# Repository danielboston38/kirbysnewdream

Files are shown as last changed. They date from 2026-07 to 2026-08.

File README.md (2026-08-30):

# Link to Video

A replacement for the RF modulator in the original Nintendo Entertainment System (NES-001). Drops into the stock RF module slot inside the shell and provides composite video and USB-C power in place of a part that fails by design.

<a href="https://certification.oshwa.org/us002842.html">
  OSHWA Certified Open Source Hardware UID US002842
</a>

> **Renamed.** This project shipped its first revision as **Kirby's New Dream**.
> From v2 onward it is **Link to Video**. Anything referring to the old name —
> the v1 board silkscreen, the 2026-07-16 PCBWay fab package under
> [`pcbway_production/`](./pcbway_production), and older commits — is the same
> project. The GitHub repository was renamed to match; the previous
> `kirbysnewdream` URL still redirects.

## Why this board exists

The NES-001's RF modulator already carries composite video, so this isn't about
adding an output the console lacks. It's about replacing a part that reliably
destroys itself.

Nintendo packed the modulator's regulator and RF stages into a sealed can with no
ventilation. It cooks its own electrolytics, they leak, and the electrolyte eats
the traces underneath. Across three NES-001 units on the author's bench, **all
three** had modulator failures from exactly this — including a Mitsumi unit that
looked pristine externally and had every capacitor leaking inside.

So the modulator is a consumable on a forty-year-old console, and the usual
options are to recap a corroded board or to fit an aftermarket board. This is the
second option, with the power input modernised to USB-C while the slot is open.

## Disclosure

This project's schematic design, debugging, and documentation were developed with the assistance of AI (Claude, by Anthropic). All hardware was hand-assembled, tested, and validated by the author. Use, review, and verify independently before building.

## Status

🟡 First prototype assembled and power-tested successfully (5V confirmed clean on rail, no protection trips). Video output path **does not work on v1 hardware** — traced to a schematic defect in which Q1's emitter node was shorted to the +5V rail (see Known Issues). Fixed in source; v1 boards need a rework.

<!-- Swap the line above for something like this once video's confirmed:
🟢 Fully validated — power and composite video both confirmed working on hardware.
-->

## Features

- USB-C power input (power only — no data lines)
- Composite video output
- Active overcurrent protection — TPS2553 eFuse with a ~1.18 A resistor-programmed limit, soft-start and thermal shutdown, backed by a polyfuse
- Fits inside the original NES shell at the stock RF module location
- Bring-up test points for video, ground, +5V and audio, labelled on the silkscreen
- Feed header for an external 8-pin mini-DIN RGB connector (NESRGB)
- All resistor and capacitor values printed on the silkscreen — the v1 board had four identical unlabelled axial footprints carrying four different values, which caused three separate wrong-resistor build errors
- 2-layer PCB, designed in KiCad

## Power path

```
USB-C  ──  F1 polyfuse  ──  U1 TPS2553 eFuse  ──  +5V rail  ──  J4.3 → NES
  VBUS      2.0A hold        ~1.18A limit          C1 100µF
            3.8A trip        soft-start            D1 TVS
            (backup)         thermal shutdown
```

F1 alone trips at 3.8 A, which protects nothing on a console that draws
roughly 0.5–0.7 A. U1 is the real protection; F1 stays as a backup in case
the eFuse ever fails short.

The current limit is set by R6 on U1's ILIM pin. The relationship is
**inverse** — a larger resistor gives a *lower* limit:

| R6 | Limit (typ) |
|---|---|
| 15 kΩ | 1700 mA |
| 20 kΩ | 1295 mA |
| **22 kΩ (fitted)** | **~1180 mA** |
| 49.9 kΩ | 520 mA |
| 210 kΩ | 130 mA |

Roughly I_OS(A) ≈ 25.9 / R6(kΩ), valid over TI's recommended 15 kΩ–232 kΩ.

U1's EN (pin 3) is active-high and tied to its own input, so the switch is
always on. FAULT (pin 4) is an open-drain output left unconnected — there is
nothing inside a closed NES shell to indicate to. If you want fault
indication, it can sink 25 mA directly.

A useful side effect: D1 is a unidirectional TVS, so fitting it backwards
puts a forward-biased diode across the 5 V rail. Before U1 that was a near
short relying on a polyfuse taking seconds to react. Now the eFuse current-
limits it at ~1.18 A and thermally shuts down, so the mistake is
self-limiting rather than destructive.

## Test points (v2)

Four through-hole test points (2.0 mm pad, 1.0 mm drill) for bring-up. They accept
a 0.64 mm square header pin, so you can solder pins in and use scope grabbers.

The silkscreen carries the signal name only — `VIDEO`, `GND`, `+5V`, `AUDIO` — so
the board reads without this table. The refdes lives on F.Fab for the fab drawings.
(On v2's first pass this was backwards: the signal names were on F.Fab, which never
reaches the physical board, so the silkscreen said only `TP1`–`TP4`.)

| TP  | Net | Location (mm) | Notes |
|-----|---|---|---|
| TP1 | `/VIDEO_OUT` | 62.0, 60.0 | Jack-side video, i.e. after C2 and the 75 Ω series R5 — what the TV actually sees. A high-impedance probe reads roughly double the terminated amplitude. |
| TP2 | `GND` | 58.5, 60.0 | Straight into the B.Cu ground pour. |
| TP3 | `/5V` | 52.0, 43.1 | Sits directly on the protected 5 V trunk, downstream of F1 and the TPS2553. |
| TP4 | `/AUDIO_OUT` | 65.9, 28.35 | Audio pass-through between J4 pin 2 and J2. |

The whole back layer is a ground pour, so TP2's position is a convenience, not a
constraint — you can clip a ground lead to any B.Cu feature.

To probe the buffer itself rather than its output, use Q1's emitter leg directly;
there is no test point on `Net-(Q1-E)`.

## RGB output (v2)

Provision for the [NESRGB](https://etim.net.au/nesrgb/) board's RGB connector —
the Micomsoft XRGB-mini Framemeister 8-pin mini-DIN standard.

The connector itself is **not** on this board. The NESRGB kit ships it as a
panel-mount jack that epoxies into a 12 mm hole in the shell, so this board just
feeds it. R/G/B run directly from the NESRGB to the connector; we supply the
other three pins on **J5**:

| J5 pin | Net | mini-DIN pin | |
|---|---|---|---|
| 1 | `/RGB_VIDEO` | 3 | Composite video / sync, 75 Ω terminated |
| 2 | `GND` | 4 | |
| 3 | `/5V` | 5 | Downstream of the TPS2553, so it is current-limited |

mini-DIN pins 1 and 2 are N/C; pins 6, 7 and 8 are Blue, Green and Red from the
NESRGB. Note the standard carries no audio — that stays on the RCA jack, which is
deliberate on Tim Worthington's part (it keeps video noise out of the audio).

**Why R7 exists.** The video buffer's output (`/VIDEO_BUF`, Q1's emitter through
C2) now feeds two outputs. Each needs its own 75 Ω source termination: R5 for the
RCA jack, R7 for the mini-DIN. Tying both to one resistor would put two 75 Ω loads
in parallel and halve the amplitude whenever both cables are plugged in.

**One output at a time.** Composite and RGB are an either/or — the design does not
target using both at once. Whichever cable is plugged sees a correct 75 Ω source,
and the unused branch is an unloaded stub.

If both are ever plugged in simultaneously, R7 means each still gets a properly
terminated 75 Ω source rather than the halved amplitude you'd get from sharing one
resistor. Q1's drive is the limit in that case, and it is why **R1 is 220 Ω from
v2** rather than the original 330 Ω. Simulated in ngspice with 2 Vpp at the tap
and both outputs terminated: at 330 Ω the follower clips the positive (white)
peaks by 33 %, at 220 Ω by 11 %. With a single output loaded — the supported
mode — 220 Ω is clean and symmetric (+0.439 / −0.447 V at the jack). Simulated,
not measured on hardware, and still not a supported mode.

## Hardware

- Designed in KiCad (schematic + PCB source included in this repo)
- Fabricated via PCBWay
- See [BOM.csv](./BOM.csv) for full parts list

## Build Notes / Known Issues (v1)

- **Q1 emitter node shorted to +5V (breaks video).** Q1's emitter is clamped to the rail, so C2 couples +5V — not video — into R5/J3. The exact wiring differs by revision: in the repo's pre-v1.1 source R1 had *both* ends on `/5V`, while the fabbed 2026-07-16 boards have R1 pad 1 on `/5V` and pad 2 on a separate net with C1 only. Root cause: an R2 (110Ω) was deleted from the schematic on 2026-07-04, and KiCad merged the two leftover collinear wire stubs into one wire, welding the emitter node to `/5V`. Fixed in source as of v1.1. **Rework for an existing board** (applies to the boards fabbed from the 2026-07-16 gerbers, whose IPC netlist reads `/5V = J4.3, F1.1, R1.1, Q1.1, C2.1, D1.1` and `Net-(C1-Pad1) = R1.2, C1.1`):

That revision has two defects — Q1's emitter is clamped to the rail, *and* C1 only reaches the rail through R1, so the bulk cap decouples nothing. Both are fixed together:

**Confirm the diagnosis before you cut.** Power off, unplugged, caps discharged.
Probe +5 V at J4 pin 3 or D1's K-marked lead. Two measurements, mirror images of
each other:

| Measurement | Defective board | Correctly wired |
|---|---|---|
| Q1 emitter → +5 V | **~0 Ω** | ~330 Ω (R1) |
| C1 **+** terminal → +5 V | **~330 Ω** (stranded behind R1) | ~0 Ω |

After the rework these swap. To identify Q1's legs without relying on the TO-92
orientation: the leg reading 0 Ω to GND is the collector, the leg with continuity
to J4 pin 1 is the base, and the remaining one is the emitter.

Two tests that look useful but are not:

- **Emitter → J3 tip.** C2 blocks DC, so this reads open either way.
- **C1 + → Q1 emitter.** Reads ~330 Ω on a good board *and* a bad one, because R1
  sits between them in both wirings. It cannot distinguish the two.

Powered, the fastest single check is DC at Q1's emitter: roughly 1.5–3 V if
correct, sitting at exactly the rail voltage if shorted.

**R1's left pad is a star point.** Three things meet there: F1 (the source), the
D1 + J4.3 branch (the load), and Q1's emitter. The two incoming rail traces are
*collinear*, so a single cut severs both — which is why this needs **two**
jumpers, not one.

1. **Cut** the 0.8 mm trace leaving R1's left pad toward the **upper left**, about
   5–8 mm from the pad. Leave the trace entering from the upper right — that is
   Q1's emitter and must stay. Stay below the level of D1's cathode; above that
   point only one of the two overlapping traces is present, and you need both cut.

2. **Two jumpers.** The cut leaves three islands that must all become one rail:

   | Island | Pads |
   |---|---|
   | A | C1's **+** pad, R1's **right** pad |
   | B | F1 pad 1 (left pad, trace toward D1 — not the USB-C side) |
   | C | D1's cathode (K), J4 pin 3 |

   Any two wires joining all three work. One wire per pad:
   - **C1+ → F1 pad 1** (~14 mm)
   - **R1's right pad → D1 cathode** (~25 mm)

   Do this with R1 removed — its right pad is far easier to solder empty.

3. **Fit R1 = 300–330 Ω.** Check the part before fitting: R1, R3, R4, R5 (and R7
   on v2) all share the same `R_Axial_DIN0207` footprint in four different values,
   and the v1 silkscreen prints no values. At least one board was built with a
   5.1 kΩ from the R3/R4 pile in R1, which gives ~0.6 mA of standing current
   instead of ~9 mA — enough to look plausible and still produce no usable video.

4. **Confirm R5 (75Ω) is populated.** Across R5's own pads should read ~75 Ω; it
   has no parallel path in circuit (C2 blocks DC on one side, the jack is open on
   the other), so it doubles as a meter sanity check.

5. **Fit the transistor last.** Powering the board before the cut is done drives
   Q1 into saturation from the rail straight to ground with no current limit — see
   below.

Verify with a meter before powering: R1's left pad to D1 cathode must now read
**open**; R1's left pad to F1 pad 1 must read **~330Ω** through R1; R1's left pad
must still show continuity to Q1's emitter and C2 pin 1; and D1's cathode must
read **~0 Ω** to J4 pin 3 *and* to F1 pad 1. Powered, Q1's emitter should sit near
1.5–3V — a reading of 5V means the cut did not take.

**The short destroys transistors.** With the emitter clamped to +5 V and the base
at the NES's video level, the B-E junction is forward-biased by 3–4 V, so Q1
saturates with its collector tied directly to ground and nothing limiting the
current. Q1 is a 150 mA part; F1 does not trip until 3.8 A. Every power-up in that
state risks another transistor, which is the likely fate of the first one.
- F1 (polyfuse) footprint field in KiCad is mislabeled as a polarized capacitor footprint despite correct value — cosmetic/documentation issue only, does not affect function. Fix planned for v2.
- Video/audio RCA jack mounting holes are slightly asymmetric — cosmetic only, doesn't affect NES shell fit.
- v1 silkscreen doesn't include component value labels or Q1 pin markers (E/C/B). **Values are on the silkscreen from v2.** On v1 this caused three separate wrong-resistor errors in R1 (a 5.1kΩ and an 820Ω both fitted before the right value went in) because R1/R3/R4/R5/R7 share one footprint across four values. Q1 pin markers are still outstanding.
- **D1 does not protect U1.** The fitted TVS is a Littelfuse 1.5KE6.8A: stand-off 5.80 V, breakdown 6.45–7.14 V at 10 mA, clamping 10.5 V at 144.8 A. The TPS2553's absolute maximum on IN and OUT is 7 V, so the TVS has barely begun conducting by the time the eFuse is already out of spec, and under a real surge it lets the rail reach 10.5 V. D1 protects the console downstream; it will not save U1. Repositioning D1 doesn't help — both U1 pins share the same 7 V rating — and no avalanche TVS clamps below 7 V while standing off USB-C's 5.5 V worst case. Proper protection needs a switch with integrated overvoltage cutoff. Deferred to v3 — v2 ships with this gap.
- D1's symbol (`Diode:1.5KExxA`) names both pins A1/A2 and draws no cathode — KiCad uses identical pin naming for the unidirectional and bidirectional variants of this part. Polarity comes only from the footprint silkscreen band, which is at the pad-1 (+5 V) end and is correct. Watch this when hand-assembling.

## Video input biasing

Q1's base is DC-coupled straight to the NES video line, with no bias network on
this board. That is deliberate, and it took a long bench session to establish
why it works.

**The NES mainboard supplies a 1 kΩ pulldown on its video output pin.** Measured
in circuit at 0.999 kΩ, identical with the meter leads both ways — a real
resistor, not a semiconductor junction. Q1's base sources roughly 46 µA, which
that 1 kΩ absorbs in about 46 mV. The base cannot float up and Q1 cannot cut off.

This is the same reason Nintendo's own modulator has no base pulldown either. It
also matches the load Nintendo presented on that pin: a 330 Ω series resistor
into a 5.6 kΩ / 330 Ω divider, roughly 500 Ω in total. The NES is built to drive
a few hundred ohms.

**So no base pulldown, and no input coupling cap.** If you are adapting this
design to something other than an NES-001, measure that pin to ground first —
if it reads open, you need a pulldown (~47 kΩ) and this board does not have one.

**R2 (330 Ω) is not a bias resistor.** It sits in series between J4 pin 1 and
Q1's base, mirroring the 330 Ω Nintendo places in the same position. Against
Q1's ~21 kΩ base input impedance it costs nothing in signal terms; what it buys
is fault-current limiting into the base-emitter junction, whose reverse rating
is only 5 V.

## Design checks

Two safety nets sit alongside ERC and DRC, both aimed at faults this board has
actually shipped with.

### `tools/check_nets.py`

```
python3 tools/check_nets.py
```

Exports the schematic netlist, reads the PCB's pad nets, confirms the two agree,
and asserts a set of invariants — chief among them that **Q1's emitter is not on
any power net**. That was the v1 fault: the emitter follower's output was tied
to +5V along with J4.3, D1.1 and F1.1, so Q1 saturated into a grounded collector
with nothing limiting the current. It destroyed a transistor on every power-up.

**ERC and DRC both passed cleanly on that board.** Neither can see that a net is
*wrong*, only that it is internally consistent — which is exactly why this check
exists. Run it before generating a fab package. Gerbers carry no net information,
so once you have them the mistake is invisible.

### `nes_power_video.kicad_dru`

Custom DRC rules covering the geometric half: extra clearance between Q1's
emitter and base nodes and the supply rails, and between the two USB-C
configuration channels. These catch the layout-adjacency version of the same
mistakes. They cannot catch a wrong net assignment — DRC has no view of design
intent — which is what the script above is for.

## Assembly

<!-- Add step-by-step or reference photos here once you've got a documented build process -->

Refer to BOM.csv for exact part values and footprints. Every component carries
its sourcing data in two places, kept in step: the `Manufacturer`, `MPN`,
`LCSC`, `Supplier Link` and `Datasheet` fields on the schematic symbol, and
the matching columns in `BOM.csv`. Jellybean passives have no manufacturer
part number by design — they carry a `Spec` field instead (tolerance, rating,
package) and any part meeting it will do. To pull the fields straight out of
the schematic:

```
kicad-cli sch export bom --group-by '' \
    --fields 'Reference,Value,Manufacturer,MPN,LCSC,Datasheet,Supplier Link,Spec' \
    -o bom.csv nes_power_video.kicad_sch
```

Key notes:
- D1 (zener/TVS): cathode (banded end) toward VBUS/+5V side. From v2 the
  silkscreen prints the value actually fitted, `1.5KE6.8A`; before that it
  printed the generic KiCad symbol name `1.5KExxA`, which is not orderable.
- Q1 (**2SA733**, PNP): flat side facing viewer, leads down = Emitter-Collector-Base, left to right.
  This replaces the 2SA1015/KSA1015, **both of which are end of life** (checked 2026-08-29): MCC's
  `2SA1015-GR-AP` is stocked at Mouser but flagged End of Life, and every onsemi `KSA1015` reads
  Obsolete on DigiKey, available only through Rochester Electronics' last-time-buy channel. The
  2SA733 is in current production, shares the E-C-B pin order exactly so it drops straight in, and is
  a better part for a video buffer: f_T 190 MHz typ against the 2SA1015's 80 MHz, C_ob 2–3 pF, P_C
  750 mW, with the same V_CEO −50 V / I_C −150 mA / V_EBO −5 V — so R2 still guards the base-emitter
  junction exactly as before. Buy the UTC `2SA733L-P-T92-B` from LCSC (**C5310429**, ~$0.035); rank P
  is hFE 200–400, which matches the ~46 µA base current measured on the bench, so the bias point does
  not move. DigiKey's Renesas 2SA733 is Rochester stock at $1.90 — same trap, different part.
- **Why not a 2N3906 or BC557?** Not for the reason you might assume. Electrically the 2N3906 is
  perfectly happy here — V_CEO −40 V, I_C −200 mA, f_T 250 MHz, V_EBO −5 V, hFE 100–300 at 10 mA,
  every figure with huge margin against a 5 V rail at ~9.3 mA. The problem is the middle pin. Per
  UTC's ordering tables, the 2N3906 is **E-B-C** and the 2SA733 is **E-C-B**: the 3906 puts *base* in
  the centre where this board wants *collector*. Turning the part around gives C-B-E — base is still
  in the middle, so no orientation fixes it and you would have to cross two leads. On a v3 layout the
  pin order is free and the 2N3906 becomes a fine choice; on this board it is not. Pin order is a
  manufacturer's choice rather than a standard, so check the datasheet of the exact brand you buy.
- R1 (220Ω): emitter load for Q1 — one end to +5V, the other to the Q1 emitter / C2 node. Not both ends to +5V. Lowered from 300Ω in v2 to raise the drive current: at the assumed ~1.3 V base, 300–330Ω supplies only ~6.2 mA at peak white against the ~6.7 mA the 150Ω load wants. Retune if the measured DC at J4 pin 1 differs from ~1.3 V.
- R2 (330Ω): series resistor in the video input line, between J4 pin 1 and Q1's base. See [Video input biasing](#video-input-biasing).
- **Trim all through-hole leads flush.** The board sits in the RF module slot with shielding immediately below it. Long clipped leads on the underside will short against the can — on the prototype this presented as an intermittent supply trip that only appeared when the board was moved.
- C2 (470µF): not 100µF. Into the 150Ω load, 100µF gives τ=15 ms against the 16.7 ms field period and tilts the picture top to bottom. 470µF gives τ=70 ms.
- F1 (polyfuse): sits with slight standoff above PCB by design — this is normal for radial-lead parts, not a defect.
  **No KiCad footprint exists for the Littelfuse RHEF series**, so F1 borrows `Fuse:Fuse_Bourns_MF-RG300`:
  pads 5.24 mm centre-to-centre with 1.01 mm drills. The RHEF200's 0.51 mm leads at 5.05 ±0.75 mm
  spacing fit that comfortably, but the Bourns device is rated 3.0 A/5.1 A and the silkscreen outline is
  *its* body — treat the outline as indicative, not as a clearance boundary. Drawing a true RHEF200
  footprint would move pad 2 by ~1.2 mm and force a re-route, so it is a v3 job, not a patch.
- USB-C1: GCT USB4970-00-A, SMD receptacle — power-only, no data lines. KiCad has no USB4970
  footprint, but GCT's USB4970 drawing specifies the same recommended land pattern as the USB4125
  (pad centres 1.00/3.04/5.50 mm, shell holes 8.64 × 3.80 mm apart), so
  `Connector_USB:USB_C_Receptacle_GCT_USB4125-xx-x` is the right footprint. Use the **plain** variant:
  USB4970-00-A takes the 1.00 mm shell stake, and `-0190` is the 1.90 mm stake part. Pad geometry is
  identical between the two, so this is a naming correction, not a layout change.
- U1 (TPS2553, SOT-23-6): pin 1 is IN, marked by the dot on the package. Pin order is IN, GND, EN down one side and OUT, ILIM, FAULT up the other. Order the plain TPS2553DBVR — the `-1` suffix is the latch-off variant, which would need a power cycle after every trip instead of retrying automatically.
- C3 (100nF, 0805): TI requires this as close to U1 pin 1 as the layout allows. It sits immediately left of U1.
- R6 (22k, 0805): sets the current limit — see the table above before substituting.

## Certification

This project is **OSHWA-certified open source hardware**, UID **[US002842](https://certification.oshwa.org/us002842.html)**.

The certification confirms that the design files, schematics, PCB layout, bill of
materials and documentation in this repository are published under an
OSI/FSF-approved open licence and are complete enough for someone else to study,
modify, manufacture and distribute the hardware. See the
[OSHWA certification directory entry](https://certification.oshwa.org/us002842.html)
for the registered details.

The certification mark above is
[`certification-mark-US002842-stacked.svg`](./certification-mark-US002842-stacked.svg),
issued by OSHWA for this UID. It applies to this design only — it is not
transferable to derivatives, which need their own certification.

## License

Licensed under [CERN-OHL-S v2](./LICENSE.txt) (strongly reciprocal open hardware license). See [LICENSE](./LICENSE.txt).

## Photos

<!-- Add build photos here -->

## Acknowledgments

<!-- Optional: credit anyone who helped with debugging, Discord community, etc. -->

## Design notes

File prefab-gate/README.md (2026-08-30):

# prefab-gate

A pre-fabrication gate for KiCad PCBs. It refuses to produce a fab package
from a board that has not passed verification.

It runs `kicad-cli` DRC with zone refill and schematic parity checking,
classifies every finding as blocking or cosmetic, and — only when nothing
blocks — exports gerbers, drill files, CPL and BOM into a manifested package.

## Subcommands

    python3 scripts/prefab_gate.py check <board.kicad_pcb>
    python3 scripts/prefab_gate.py package <board.kicad_pcb> [--out fab]

Installed as a Claude Code plugin, use `${CLAUDE_PLUGIN_ROOT}/scripts/prefab_gate.py`.

`check` runs DRC and parity, prints a verdict, and exits — no package is
written. It still runs with `--refill-zones --save-board`, so it can rewrite
the board's zone fills; it says so when it does.
`package` does the same, and if the verdict passes, exports the fab package
and writes a `manifest.json` alongside it recording the board hash, the
kicad-cli version, and every finding (including waived cosmetic ones).

Both accept `--json` to also print the verdict as JSON, and `--strict` to
treat findings that are normally cosmetic more conservatively.

## Schematic parity

`kicad-cli` exits 0 and reports an empty parity result when it cannot load the
schematic, so "clean" and "never ran" are indistinguishable from its output
alone. The gate closes that hole with a `parity_not_run` finding.

It locates the schematic beside the board under the board's own name, else a
sole `*.kicad_sch` in that directory. Failing that — including when several
candidates make the choice ambiguous — `parity_not_run` **blocks**, naming what
was tried.

- `--schematic PATH` — say where the schematic is.
- `--no-parity` — accept a PCB-only check. The finding is still recorded, as
  cosmetic, in both the report and the manifest. `--strict` overrides it.

`kicad-cli pcb drc` derives the schematic from the board's basename with no way
to override it, so a differently-named schematic must be renamed for parity to
actually run. The manifest records whether parity ran, against which schematic,
or why it did not.

## Exit codes

- `0` — clean (and, for `package`, packaged)
- `2` — blocked; at least one blocking finding, no files written. This includes
  a board kicad-cli runs but cannot load (a truncated file, items on undefined
  layers): that is a `board_unreadable` finding about the board, not a broken
  install, so it belongs here rather than in `3`.
- `3` — the gate could not run: kicad-cli missing, unreachable or too old, the
  board missing, `--schematic` pointing at nothing, unreadable DRC output, or a
  usage error.
  Usage errors take `3` rather than argparse's default `2` so CI can tell a
  mistyped flag from a board that failed verification.

## Installing as a plugin

    /plugin marketplace add danielboston38/linktovideo
    /plugin install prefab-gate@prefab-gate

Plugin metadata lives here in `prefab-gate/.claude-plugin/plugin.json`. The
marketplace manifest is at the **repository root**, in
`.claude-plugin/marketplace.json`, pointing back at this directory with
`"source": "./prefab-gate"` — a marketplace is added by bare repo reference,
so the loader looks only at the root and finds nothing in a subdirectory.

## Licence

The plugin is MIT — see `LICENSE` in this directory. The hardware in the rest
of the repository is CERN-OHL-S-2.0 under the root `LICENSE.txt`. Separate
works, separate terms.

## kicad-cli

Requires `kicad-cli` on `PATH`, or point `KICAD_CLI` at its full path, e.g.
on macOS:

    export KICAD_CLI=/Applications/KiCad/KiCad.app/Contents/MacOS/kicad-cli

DRC runs with `--refill-zones --save-board`, which can rewrite zone fills in
the board file in place; the gate hashes the board before and after and
notes it when this happens.

## Tests

Stdlib `unittest` only — no pytest, no third-party dependencies.

    cd scripts && PYTHONPATH=. python3 -m unittest discover -s ../tests -p 'test_*.py' -v

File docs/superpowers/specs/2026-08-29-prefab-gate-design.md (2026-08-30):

# Pre-fab gate — design

**Date:** 2026-08-29
**Status:** approved for planning
**Author:** Mark (with Claude Opus 5)

## Problem

Nothing in the current toolchain can stop a bad fab package from shipping.

On 2026-08-28 this project's board had `/AUDIO_OUT` shorted to the GND pour — a
stale zone fill left behind when J2 was rotated — and `tools/check_nets.py`
passed clean, because it only compares net *membership* between schematic and
PCB and cannot see copper geometry at all. KiCad keeps serving the previously
serialised fill polygon until something refills it.

kicad-happy cannot catch this either, and not by oversight: it invokes
`kicad-cli` in zero Python files, by design ("KiCad not required at runtime").
That means it can only read serialised fills, never recompute them.

A second class of fault was found on 2026-08-29 while designing this gate:
running DRC with `--schematic-parity` — a flag nothing in this repo had ever
passed — reported 30 parity issues, including a `dnp` attribute on both RCA
jacks that the schematic did not share.

That one is instructive, because the flag was not a mistake. It was set
deliberately, when the plan was to have PCBWay assemble the SMD parts only and
leave the through-hole jacks unfitted. The plan later changed; the PCB kept the
flag and the schematic never had it. Nobody typed anything wrong — a decision
was reversed and only one side of the design heard about it.

This is the failure mode parity checking actually defends against: not typos,
but **drift between two representations of the same intent**. It is also why a
DNP mismatch blocks rather than warns. The gate cannot know which side is
right — only that the two disagree about whether a part gets fitted, which is
not a question to resolve at the assembler.

## What this is

A distributable Claude Code plugin providing one CLI that refuses to produce a
fab package from a board that has not passed verification.

The gate **owns the export**. Verification and packaging are one operation, so
the check cannot be skipped and a stale package is structurally impossible —
the gerbers are always produced from the state that just passed.

## Decisions

| Decision | Choice | Why |
|---|---|---|
| Audience | Distributable plugin | The gap is in kicad-happy generally, not just this board |
| Enforcement | Gate owns the export | Un-skippable; removes staleness as a category |
| DRC policy | Respect KiCad's own severities | No second config language; honours a decision already made in the GUI |
| Parity policy | Split by sub-type | A footprint mismatch can ruin a board; a missing MPN field cannot |
| Output | Gerbers + drill + BOM + CPL | Matches the existing `pcbway_production/<timestamp>/` layout |
| Zone fills | Refill and save the board | Fixes the stale fill at source; board and package always agree |
| Shape | One CLI, subcommands | Matches "gate owns export" without inventing a hash protocol |

## Structure

```
prefab-gate/
├── plugin.json                     marketplace metadata
├── skills/prefab-gate/SKILL.md     when to use it, how to read a verdict
├── scripts/prefab_gate.py          the gate
└── tests/                          unit + fixture boards
```

Internally split into small units, each independently testable: `locate_cli`,
`run_drc`, `classify`, `export_package`, `report`.

## CLI

```
prefab_gate.py check   <board.kicad_pcb>   verify only, produces no package
prefab_gate.py package <board.kicad_pcb>   check then export — the un-skippable path
```

A standalone `export` subcommand was considered and dropped: an export that
could run without a check would reintroduce exactly the skip this gate exists to
prevent, and one that re-runs the check itself is just `package` under another
name.

`check` produces no *package*, but it is not read-only: DRC runs with
`--refill-zones --save-board` on both subcommands, per the Decisions table, so
`check` can rewrite the board's zone fills. That is deliberate — a stale fill is
the fault this gate exists to catch, and a `check` that left it stale would
report on a board nobody is going to fabricate. The gate hashes the board either
side and announces the change, so the resulting git diff is expected rather than
mysterious.

Flags:

| Flag | Meaning |
|---|---|
| `--out <dir>` | package destination, default `fab/` |
| `--json` | machine-readable verdict on stdout in addition to the report |
| `--strict` | treat cosmetic findings as blocking too — for a final pre-order run |
| `--schematic <path>` | schematic to check parity against, when it is not the board's conventional sibling |
| `--no-parity` | skip schematic parity; recorded as a cosmetic `parity_not_run` finding, never silently |

Exit codes: `0` clean · `2` blocked by findings · `3` environment problem.

## Data flow (`package`)

1. Locate `kicad-cli`: `$KICAD_CLI`, then `PATH`, then platform-standard paths.
2. One DRC invocation:
   `--format json --severity-all --schematic-parity --refill-zones --save-board`
   This yields violations, unconnected items and parity together, and leaves the
   board's zones correctly filled.
3. Classify every finding as blocking or cosmetic.
4. On any blocking finding: print the report, exit `2`, **produce no files**. A
   half-written package directory is its own hazard.
5. Otherwise export gerbers, drill, BOM and CPL into `<out>/<timestamp>/`,
   building in a temp directory and renaming on success so failure never leaves
   something that looks shippable.
6. Write `manifest.json` beside the package.

## Classification

**DRC violations** — `error` blocks, `warning` is cosmetic, exclusions are
counted and otherwise ignored, and **any other severity — including an absent
one — blocks**, for the same reason an unrecognised parity description does.
**Unconnected items** always block.

The exclusion count and the project file's `ignored_checks` both reach the
verdict, the report and the manifest. A gate that prints PASSED without saying
which checks were switched off is overstating its own coverage.

**Schematic parity** — the JSON `type` field is *not* sufficient.
`footprint_symbol_mismatch` covers both "doesn't match footprint given by
symbol" (structural) and "'Exclude from bill of materials' settings differ"
(metadata). Classification therefore matches on description text, which is
fragile across KiCad versions, so:

**Any parity description the classifier does not recognise blocks**, naming the
exact unmatched string. A gate that fails open on an unfamiliar message is not a
gate.

| Class | Findings |
|---|---|
| Blocking | footprint doesn't match symbol; footprint missing/extra; net mismatch; **DNP differs** |
| Cosmetic | missing symbol field; exclude-from-BOM differs |

## manifest.json

Written beside every package. Records `kicad-cli` version, the board's SHA-256
at export time, the complete verdict including every cosmetic finding waved
through, and a checksum per exported file.

This answers, months later: what exactly was sent, from which board state, and
what did the gate knowingly allow past? Re-hashing the board says immediately
whether the package still corresponds to it.

## Error handling

- Exit `3` covers every way the gate could not run, never a verdict about the
  board: `kicad-cli` missing or too old, the board or its schematic missing,
  unparseable DRC output, an unwritable package — and usage errors, which take
  `3` rather than argparse's default `2` so CI can tell a mistyped flag from a
  board that failed verification.
- **Schematic parity fails closed, as a finding.** `kicad-cli pcb drc
  --schematic-parity` exits `0` and emits `"schematic_parity": []` when it
  cannot load the schematic, printing only to stderr. A clean parity result
  that means "parity never ran" is the exact fault class this tool exists to
  catch.

  Refusing to start would be the wrong remedy: measured across a 493-board
  corpus, **17.8% of real KiCad projects have no `.kicad_sch` under the board's
  own basename** (78 with none in that directory, 10 under a different name).
  A gate that will not start on one project in five is not a gate either.

  So the gate locates the schematic — the conventional sibling, else a sole
  `*.kicad_sch` beside the board, else nothing rather than a guess among
  several — and when it cannot, synthesises a **blocking `parity_not_run`
  finding** naming what it tried. `--schematic PATH` overrides the search;
  `--no-parity` records the same finding as **cosmetic**, so a PCB-only design
  can be gated deliberately but never silently. The stderr markers produce the
  same finding: the violations in that report are still valid, so it is a
  finding about the board, not an environment failure.

  The manifest records whether parity ran, against which schematic, or why not.

  Note that `kicad-cli pcb drc` derives the schematic from the board's basename
  and offers no override, so `--schematic` cannot make a differently-named
  schematic work — it must be renamed. The gate reports that rather than
  pretending otherwise.
- `kicad-cli` missing or too old → exit `3` with platform-specific install
  hints. This plugin *requires* KiCad, the opposite of kicad-happy's premise, so
  the failure must be loud rather than a silent degrade.
- Capability is feature-probed rather than version-parsed: the gate runs
  `kicad-cli pcb drc --help` once and requires `--format`, `--schematic-parity`
  and `--refill-zones` to be present. This avoids pinning a version number that
  would be wrong on distro builds and nightlies, and it fails with a message
  naming the missing flag.
- `--exit-code-violations` is deliberately not used; the gate parses the JSON and
  applies its own policy.
- `--save-board` mutates the board, so the gate hashes it before and after and
  states plainly when the refill changed it — the git diff should be expected,
  not mysterious.

## Testing

Unit tests drive `classify` with synthetic DRC JSON: every severity, both parity
classes, and an unrecognised description that must block.

Integration tests use fixture boards — one deliberately broken that must fail,
one clean that must produce a complete package with a valid manifest.

**Acceptance test.** `nes_power_video.kicad_pcb` at commit `c37b56b` must yield
exactly:

```
BLOCK  courtyards_overlap               TP1/J3     (error)
BLOCK  footprint_symbol_mismatch        J5         (footprint id mismatch)
pass   silk_edge_clearance        x4               (warning)
pass   silk_overlap               x2               (warning)
pass   footprint_symbol_field_mismatch x23         (metadata)
pass   exclude-from-BOM differs   x4    TP1-TP4    (metadata)
```

Two blockers, thirty-three passed with a note — 4 + 2 + 23 + 4, which is what
the table above sums to. (An earlier draft of this document said twenty-nine,
which never matched its own table; the real verdict has been verified twice
against the board. Do not "fix" the gate to reproduce the wrong number.) Any
other verdict means the gate is wrong.

## Out of scope

- Fab-house profiles (JLCPCB vs PCBWay drill formats, CPL column names). Deferred
  until the core gate is proven; this is where such tools accrete per-vendor
  breakage.
- Exported drill/copper diffing against the board. Made redundant by the gate
  owning the export.
- Replacing `tools/check_nets.py`. Its design-intent invariants are complementary
  and stay as they are.

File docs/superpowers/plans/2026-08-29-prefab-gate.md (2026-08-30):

# Pre-fab Gate Implementation Plan

> **For agentic workers:** REQUIRED SUB-SKILL: Use superpowers:subagent-driven-development (recommended) or superpowers:executing-plans to implement this plan task-by-task. Steps use checkbox (`- [ ]`) syntax for tracking.

**Goal:** A distributable Claude Code plugin whose CLI refuses to produce a fab package from a board that has not passed verification.

**Architecture:** One CLI entry point (`prefab_gate.py`) over a small package of single-responsibility modules. A single `kicad-cli pcb drc` invocation yields violations, unconnected items and schematic parity together; a pure `classify()` function turns that JSON into a verdict; export only runs when the verdict is clean, builds into a temp directory, and renames on success.

**Tech Stack:** Python 3.10+, standard library only. `kicad-cli` (KiCad 8+) as an external dependency. Tests via `python3 -m unittest` — no pytest, no pip install.

**Spec:** `docs/superpowers/specs/2026-08-29-prefab-gate-design.md`

## Global Constraints

- **Python 3.10+, standard library only.** No pip installs, no third-party imports, in the plugin or its tests. Matches kicad-happy's hard requirement so the plugin runs anywhere with a Python interpreter.
- **`kicad-cli` is required, never optional.** Missing or incapable → exit `3` with a message naming what is missing.
- **Capability is feature-probed, not version-parsed.** `kicad-cli pcb drc --help` must advertise `--format`, `--schematic-parity` and `--refill-zones`.
- **Exit codes:** `0` clean · `2` blocked by findings · `3` environment problem.
- **Unrecognised parity descriptions block**, naming the exact unmatched string.
- **No files on a blocking verdict.** Not even a partial directory.
- **Export is atomic:** build in a temp directory, `os.replace` into place on success.
- **Build location:** `prefab-gate/` at the repo root. Extraction into its own publishable repo is a mechanical `git init` of that directory and is deliberately not part of this plan.

## File Structure

| File | Responsibility |
|---|---|
| `prefab-gate/scripts/prefab_gate.py` | CLI: argument parsing, subcommand dispatch, exit codes |
| `prefab-gate/scripts/gate/model.py` | `Finding` and `Verdict` dataclasses |
| `prefab-gate/scripts/gate/classify.py` | Pure DRC-JSON → `Verdict`. No I/O |
| `prefab-gate/scripts/gate/kicad.py` | Locate `kicad-cli`, probe capability, run DRC |
| `prefab-gate/scripts/gate/report.py` | Human-readable and JSON renderings of a `Verdict` |
| `prefab-gate/scripts/gate/manifest.py` | Hashing and manifest construction |
| `prefab-gate/scripts/gate/export.py` | Atomic package export |
| `prefab-gate/skills/prefab-gate/SKILL.md` | When to reach for the gate, how to read a verdict |
| `prefab-gate/.claude-plugin/plugin.json` | Plugin metadata — Claude Code loads it from `.claude-plugin/`, not the plugin root |
| `.claude-plugin/marketplace.json` | Single-plugin marketplace metadata. **At the repository root, not inside the plugin** — a marketplace is added by bare repo reference, so the loader looks only at the root and finds nothing in a subdirectory. Its entry points back with `"source": "./prefab-gate"`. |
| `prefab-gate/tests/` | Unit tests, one module per source module |

`classify.py` is deliberately pure: it takes parsed JSON and returns a verdict, touching no filesystem and no subprocess. That is what makes the policy testable without KiCad installed.

---

### Task 1: Finding and Verdict model

**Files:**
- Create: `prefab-gate/scripts/gate/__init__.py` (empty)
- Create: `prefab-gate/scripts/gate/model.py`
- Test: `prefab-gate/tests/test_model.py`

**Interfaces:**
- Consumes: nothing
- Produces: `Finding(kind, type, description, severity, items, blocking, reason)` frozen dataclass; `Verdict(blocking, cosmetic)` with `.passed` property returning `bool`

- [ ] **Step 1: Write the failing test**

```python
import unittest
from gate.model import Finding, Verdict

def finding(blocking=True):
    return Finding(kind="violation", type="clearance", description="Clearance violation",
                   severity="error", items=("Track F.Cu", "Pad U1.2"),
                   blocking=blocking, reason="severity is error")

class TestVerdict(unittest.TestCase):
    def test_verdict_with_no_blocking_findings_has_passed_true(self):
        self.assertTrue(Verdict(blocking=[], cosmetic=[finding(False)]).passed)

    def test_verdict_with_a_blocking_finding_has_passed_false(self):
        self.assertFalse(Verdict(blocking=[finding()], cosmetic=[]).passed)

    def test_finding_is_hashable_so_verdicts_can_be_deduplicated(self):
        self.assertEqual(len({finding(), finding()}), 1)
```

- [ ] **Step 2: Run test to verify it fails**

Run: `cd prefab-gate/scripts && python3 -m unittest discover -s ../tests -t . -v`
Expected: FAIL with `ModuleNotFoundError: No module named 'gate'`

- [ ] **Step 3: Write minimal implementation**

```python
"""Value types for gate verdicts."""
from dataclasses import dataclass, field

@dataclass(frozen=True)
class Finding:
    kind: str          # "violation" | "unconnected" | "parity"
    type: str          # kicad-cli's machine-readable type, "" when absent
    description: str
    severity: str      # "error" | "warning" | "exclusion" | ""
    items: tuple       # tuple[str, ...] of affected item descriptions
    blocking: bool
    reason: str        # why the gate placed it in this class

@dataclass
class Verdict:
    blocking: list = field(default_factory=list)
    cosmetic: list = field(default_factory=list)

    @property
    def passed(self) -> bool:
        return not self.blocking
```

- [ ] **Step 4: Run test to verify it passes**

Run: `cd prefab-gate/scripts && python3 -m unittest discover -s ../tests -t . -v`
Expected: 3 tests PASS

- [ ] **Step 5: Commit**

```bash
git add prefab-gate/scripts/gate/__init__.py prefab-gate/scripts/gate/model.py prefab-gate/tests/test_model.py
git commit -m "feat(prefab-gate): add Finding and Verdict model"
```

---

### Task 2: Classify DRC violations and unconnected items

**Files:**
- Create: `prefab-gate/scripts/gate/classify.py`
- Test: `prefab-gate/tests/test_classify_drc.py`

**Interfaces:**
- Consumes: `Finding`, `Verdict` from Task 1
- Produces: `classify(drc: dict, strict: bool = False) -> Verdict`

- [ ] **Step 1: Write the failing test**

```python
import unittest
from gate.classify import classify

def drc(violations=(), unconnected=(), parity=()):
    return {"violations": list(violations), "unconnected_items": list(unconnected),
            "schematic_parity": list(parity)}

def violation(severity, type_="clearance"):
    return {"type": type_, "description": f"{type_} problem", "severity": severity,
            "items": [{"description": "Pad U1.2"}]}

class TestClassifyViolations(unittest.TestCase):
    def test_error_severity_blocks(self):
        v = classify(drc(violations=[violation("error")]))
        self.assertEqual(len(v.blocking), 1)
        self.assertFalse(v.passed)

    def test_warning_severity_is_cosmetic(self):
        v = classify(drc(violations=[violation("warning", "silk_overlap")]))
        self.assertEqual(len(v.cosmetic), 1)
        self.assertTrue(v.passed)

    def test_exclusion_severity_is_neither_blocking_nor_cosmetic(self):
        v = classify(drc(violations=[violation("exclusion")]))
        self.assertEqual((len(v.blocking), len(v.cosmetic)), (0, 0))

    def test_unconnected_items_always_block(self):
        v = classify(drc(unconnected=[{"description": "Net /5V", "items": []}]))
        self.assertEqual(len(v.blocking), 1)

    def test_strict_mode_promotes_cosmetic_to_blocking(self):
        v = classify(drc(violations=[violation("warning", "silk_overlap")]), strict=True)
        self.assertEqual(len(v.blocking), 1)
        self.assertEqual(len(v.cosmetic), 0)

    def test_finding_records_affected_items(self):
        v = classify(drc(violations=[violation("error")]))
        self.assertEqual(v.blocking[0].items, ("Pad U1.2",))
```

- [ ] **Step 2: Run test to verify it fails**

Run: `cd prefab-gate/scripts && python3 -m unittest tests.test_classify_drc -v`
Expected: FAIL with `ModuleNotFoundError: No module named 'gate.classify'`

- [ ] **Step 3: Write minimal implementation**

```python
"""Turn parsed kicad-cli DRC JSON into a Verdict.

Pure: no filesystem, no subprocess. That is what makes the policy testable
without KiCad installed.
"""
from gate.model import Finding, Verdict

def _items(entry):
    return tuple(i.get("description", "") for i in entry.get("items", []))

def classify(drc: dict, strict: bool = False) -> Verdict:
    verdict = Verdict()

    def place(finding):
        if finding.blocking or strict:
            verdict.blocking.append(
                finding if finding.blocking
                else Finding(**{**finding.__dict__, "blocking": True,
                                "reason": finding.reason + " (promoted by --strict)"}))
        else:
            verdict.cosmetic.append(finding)

    for v in drc.get("violations", []):
        severity = v.get("severity", "")
        if severity == "exclusion":
            continue          # user excluded it in the GUI; counted, not judged
        place(Finding(kind="violation", type=v.get("type", ""),
                      description=v.get("description", ""), severity=severity,
                      items=_items(v), blocking=(severity == "error"),
                      reason=f"DRC severity is {severity or 'unset'}"))

    for u in drc.get("unconnected_items", []):
        place(Finding(kind="unconnected", type=u.get("type", "unconnected"),
                      description=u.get("description", ""), severity="error",
                      items=_items(u), blocking=True,
                      reason="unconnected items always block"))

    return verdict
```

- [ ] **Step 4: Run test to verify it passes**

Run: `cd prefab-gate/scripts && python3 -m unittest tests.test_classify_drc -v`
Expected: 6 tests PASS

- [ ] **Step 5: Commit**

```bash
git add prefab-gate/scripts/gate/classify.py prefab-gate/tests/test_classify_drc.py
git commit -m "feat(prefab-gate): classify DRC violations by KiCad severity"
```

---

### Task 3: Classify schematic parity, blocking on anything unrecognised

**Files:**
- Modify: `prefab-gate/scripts/gate/classify.py`
- Test: `prefab-gate/tests/test_classify_parity.py`

**Interfaces:**
- Consumes: `classify()` from Task 2
- Produces: same signature; adds `BLOCKING_PARITY`, `COSMETIC_PARITY` module constants (tuples of substrings)

The `type` field is *not* sufficient here. `footprint_symbol_mismatch` covers both "doesn't match footprint given by symbol" (structural) and "'Exclude from bill of materials' settings differ" (metadata). Matching is on description substrings, and anything unmatched blocks.

Real descriptions observed on a KiCad 10 board, use these verbatim in tests:

- `Missing symbol field 'Manufacturer' in footprint`
- `Footprint attributes don't match symbol: 'Do not populate' settings differ`
- `Footprint attributes don't match symbol: 'Exclude from bill of materials' settings differ`
- `PinHeader_1x03_P2.54mm_Vertical doesn't match footprint given by symbol (Connector_PinHeader_2.54mm:PinHeader_1x03_P2.54mm_Vertical)`

- [ ] **Step 1: Write the failing test**

```python
import unittest
from gate.classify import classify

def parity(description, type_="footprint_symbol_mismatch"):
    return {"type": type_, "description": description, "severity": "warning",
            "items": [{"description": "Footprint J5"}]}

def drc(parity_entries):
    return {"violations": [], "unconnected_items": [], "schematic_parity": list(parity_entries)}

class TestClassifyParity(unittest.TestCase):
    def test_footprint_mismatch_blocks(self):
        v = classify(drc([parity(
            "PinHeader_1x03_P2.54mm_Vertical doesn't match footprint given by symbol "
            "(Connector_PinHeader_2.54mm:PinHeader_1x03_P2.54mm_Vertical)")]))
        self.assertEqual(len(v.blocking), 1)

    def test_dnp_mismatch_blocks(self):
        v = classify(drc([parity(
            "Footprint attributes don't match symbol: 'Do not populate' settings differ")]))
        self.assertEqual(len(v.blocking), 1)

    def test_missing_symbol_field_is_cosmetic(self):
        v = classify(drc([parity("Missing symbol field 'Manufacturer' in footprint",
                                 "footprint_symbol_field_mismatch")]))
        self.assertEqual(len(v.cosmetic), 1)
        self.assertTrue(v.passed)

    def test_exclude_from_bom_is_cosmetic(self):
        v = classify(drc([parity(
            "Footprint attributes don't match symbol: "
            "'Exclude from bill of materials' settings differ")]))
        self.assertEqual(len(v.cosmetic), 1)

    def test_unrecognised_description_blocks(self):
        v = classify(drc([parity("Some future KiCad wording nobody has seen")]))
        self.assertEqual(len(v.blocking), 1)

    def test_unrecognised_description_names_the_string_it_did_not_match(self):
        v = classify(drc([parity("Some future KiCad wording nobody has seen")]))
        self.assertIn("Some future KiCad wording nobody has seen", v.blocking[0].reason)
```

- [ ] **Step 2: Run test to verify it fails**

Run: `cd prefab-gate/scripts && python3 -m unittest tests.test_classify_parity -v`
Expected: FAIL — parity entries are currently ignored, so every test reports 0 findings

- [ ] **Step 3: Write minimal implementation**

Add to `classify.py`, above `classify()`:

```python
# Parity descriptions are matched by substring because kicad-cli's `type` field
# is too coarse: footprint_symbol_mismatch covers both a genuine footprint
# mismatch and a trivial exclude-from-BOM difference.
BLOCKING_PARITY = (
    "doesn't match footprint given by symbol",
    "'Do not populate' settings differ",
    "not found in schematic",
    "not found on PCB",
    "net mismatch",
)
COSMETIC_PARITY = (
    "Missing symbol field",
    "'Exclude from bill of materials' settings differ",
)
```

and inside `classify()`, before `return verdict`:

```python
    for p in drc.get("schematic_parity", []):
        description = p.get("description", "")
        if any(s in description for s in BLOCKING_PARITY):
            blocking, reason = True, "structural parity mismatch"
        elif any(s in description for s in COSMETIC_PARITY):
            blocking, reason = False, "metadata-only parity mismatch"
        else:
            blocking = True
            reason = ("unrecognised parity description, blocking by default: "
                      f"{description!r}")
        place(Finding(kind="parity", type=p.get("type", ""), description=description,
                      severity=p.get("severity", "warning"), items=_items(p),
                      blocking=blocking, reason=reason))
```

- [ ] **Step 4: Run test to verify it passes**

Run: `cd prefab-gate/scripts && python3 -m unittest discover -s ../tests -t . -v`
Expected: all 15 tests PASS

- [ ] **Step 5: Commit**

```bash
git add prefab-gate/scripts/gate/classify.py prefab-gate/tests/test_classify_parity.py
git commit -m "feat(prefab-gate): classify parity findings, block on unrecognised wording"
```

---

### Task 4: Locate kicad-cli and probe its capability

**Files:**
- Create: `prefab-gate/scripts/gate/kicad.py`
- Test: `prefab-gate/tests/test_kicad_locate.py`

**Interfaces:**
- Consumes: nothing
- Produces: `class KicadUnavailable(Exception)`; `locate_cli(env=None, which=shutil.which, exists=os.path.exists) -> str`; `probe_capability(cli, runner=subprocess.run) -> None` raising `KicadUnavailable`

Injected `which`/`exists`/`runner` keep the tests free of a real KiCad install.

- [ ] **Step 1: Write the failing test**

```python
import unittest
from gate.kicad import locate_cli, probe_capability, KicadUnavailable

HELP = ("Usage: pcb drc [--help] [--output OUTPUT_FILE] [--format FORMAT] "
        "[--schematic-parity] [--severity-all] [--refill-zones] INPUT_FILE")

class Result:
    def __init__(self, stdout="", returncode=0):
        self.stdout, self.returncode = stdout, returncode

class TestLocate(unittest.TestCase):
    def test_env_var_wins(self):
        found = locate_cli(env={"KICAD_CLI": "/custom/kicad-cli"},
                           which=lambda n: None, exists=lambda p: True)
        self.assertEqual(found, "/custom/kicad-cli")

    def test_falls_back_to_path(self):
        found = locate_cli(env={}, which=lambda n: "/usr/bin/kicad-cli",
                           exists=lambda p: False)
        self.assertEqual(found, "/usr/bin/kicad-cli")

    def test_raises_when_absent_everywhere(self):
        with self.assertRaises(KicadUnavailable) as ctx:
            locate_cli(env={}, which=lambda n: None, exists=lambda p: False)
        self.assertIn("kicad-cli", str(ctx.exception))

    def test_env_var_pointing_at_nothing_is_an_error(self):
        with self.assertRaises(KicadUnavailable):
            locate_cli(env={"KICAD_CLI": "/nope"}, which=lambda n: None,
                       exists=lambda p: False)

class TestProbe(unittest.TestCase):
    def test_accepts_a_capable_cli(self):
        probe_capability("kicad-cli", runner=lambda *a, **k: Result(HELP))

    def test_rejects_and_names_the_missing_flag(self):
        stripped = HELP.replace("[--schematic-parity] ", "")
        with self.assertRaises(KicadUnavailable) as ctx:
            probe_capability("kicad-cli", runner=lambda *a, **k: Result(stripped))
        self.assertIn("--schematic-parity", str(ctx.exception))
```

- [ ] **Step 2: Run test to verify it fails**

Run: `cd prefab-gate/scripts && python3 -m unittest tests.test_kicad_locate -v`
Expected: FAIL with `ModuleNotFoundError: No module named 'gate.kicad'`

- [ ] **Step 3: Write minimal implementation**

```python
"""Locating and driving kicad-cli."""
import os
import shutil
import subprocess

REQUIRED_FLAGS = ("--format", "--schematic-parity", "--refill-zones")

# Checked in order, after $KICAD_CLI and $PATH.
FALLBACK_PATHS = (
    "/Applications/KiCad/KiCad.app/Contents/MacOS/kicad-cli",
    "/usr/bin/kicad-cli",
    "/usr/local/bin/kicad-cli",
    r"C:\Program Files\KiCad\9.0\bin\kicad-cli.exe",
)

class KicadUnavailable(Exception):
    """kicad-cli is missing, or too old to do what the gate needs."""

def locate_cli(env=None, which=shutil.which, exists=os.path.exists) -> str:
    env = os.environ if env is None else env
    override = env.get("KICAD_CLI")
    if override:
        if exists(override):
            return override
        raise KicadUnavailable(f"KICAD_CLI is set to {override!r}, which does not exist")
    found = which("kicad-cli")
    if found:
        return found
    for candidate in FALLBACK_PATHS:
        if exists(candidate):
            return candidate
    raise KicadUnavailable(
        "kicad-cli not found. Install KiCad 8 or newer, then either put kicad-cli on "
        "your PATH or set KICAD_CLI to its full path.\n"
        "  macOS:   /Applications/KiCad/KiCad.app/Contents/MacOS/kicad-cli\n"
        "  Linux:   apt install kicad  (or the KiCad AppImage)\n"
        "  Windows: C:\\Program Files\\KiCad\\<version>\\bin\\kicad-cli.exe")

def probe_capability(cli: str, runner=subprocess.run) -> None:
    result = runner([cli, "pcb", "drc", "--help"], capture_output=True, text=True)
    help_text = getattr(result, "stdout", "") or ""
    missing = [f for f in REQUIRED_FLAGS if f not in help_text]
    if missing:
        raise KicadUnavailable(
            f"{cli} does not support {', '.join(missing)}. The gate needs KiCad 8 or "
            "newer; upgrade KiCad or point KICAD_CLI at a newer install.")
```

- [ ] **Step 4: Run test to verify it passes**

Run: `cd prefab-gate/scripts && python3 -m unittest tests.test_kicad_locate -v`
Expected: 6 tests PASS

- [ ] **Step 5: Commit**

```bash
git add prefab-gate/scripts/gate/kicad.py prefab-gate/tests/test_kicad_locate.py
git commit -m "feat(prefab-gate): locate kicad-cli and feature-probe its DRC flags"
```

---

### Task 5: Run DRC and parse its JSON

**Files:**
- Modify: `prefab-gate/scripts/gate/kicad.py`
- Test: `prefab-gate/tests/test_kicad_drc.py`

**Interfaces:**
- Consumes: `KicadUnavailable` from Task 4
- Produces: `run_drc(cli: str, board: str, runner=subprocess.run) -> dict`

`--exit-code-violations` is deliberately not passed: the gate applies its own policy, so a non-zero exit would only obscure a successful run that found problems.

- [ ] **Step 1: Write the failing test**

```python
import json
import os
import tempfile
import unittest
from gate.kicad import run_drc, KicadUnavailable

class TestRunDrc(unittest.TestCase):
    def setUp(self):
        self.calls = []

    def runner(self, payload=None, returncode=0):
        def _run(cmd, **kwargs):
            self.calls.append(cmd)
            out = cmd[cmd.index("-o") + 1]
            with open(out, "w") as fh:
                json.dump(payload if payload is not None
                          else {"violations": [], "unconnected_items": [],
                                "schematic_parity": []}, fh)

            class R:
                pass
            r = R()
            r.returncode, r.stdout, r.stderr = returncode, "", ""
            return r
        return _run

    def test_returns_parsed_json(self):
        drc = run_drc("kicad-cli", "board.kicad_pcb", runner=self.runner())
        self.assertEqual(drc["violations"], [])

    def test_passes_the_flags_the_gate_depends_on(self):
        run_drc("kicad-cli", "board.kicad_pcb", runner=self.runner())
        cmd = " ".join(self.calls[0])
        for flag in ("--format json", "--severity-all", "--schematic-parity",
                     "--refill-zones", "--save-board"):
            self.assertIn(flag, cmd)

    def test_raises_when_kicad_cli_fails(self):
        def failing(cmd, **kwargs):
            class R:
                pass
            r = R()
            r.returncode, r.stdout, r.stderr = 1, "", "boom"
            return r
        with self.assertRaises(KicadUnavailable):
            run_drc("kicad-cli", "board.kicad_pcb", runner=failing)
```

- [ ] **Step 2: Run test to verify it fails**

Run: `cd prefab-gate/scripts && python3 -m unittest tests.test_kicad_drc -v`
Expected: FAIL with `ImportError: cannot import name 'run_drc'`

- [ ] **Step 3: Write minimal implementation**

Append to `kicad.py`:

```python
import json
import tempfile

def run_drc(cli: str, board: str, runner=subprocess.run) -> dict:
    """One DRC pass: violations, unconnected items and parity together.

    --refill-zones --save-board is intentional. A stale zone fill is the fault
    this gate exists to catch, and refilling without saving would leave the
    board on disk disagreeing with the package just exported from it.
    """
    with tempfile.TemporaryDirectory() as tmp:
        out = os.path.join(tmp, "drc.json")
        result = runner([cli, "pcb", "drc", "--format", "json", "--severity-all",
                         "--schematic-parity", "--refill-zones", "--save-board",
                         "-o", out, board],
                        capture_output=True, text=True)
        if getattr(result, "returncode", 0) != 0:
            raise KicadUnavailable(
                f"kicad-cli DRC failed (exit {result.returncode}): "
                f"{(getattr(result, 'stderr', '') or '').strip()}")
        with open(out) as fh:
            return json.load(fh)
```

- [ ] **Step 4: Run test to verify it passes**

Run: `cd prefab-gate/scripts && python3 -m unittest tests.test_kicad_drc -v`
Expected: 3 tests PASS

- [ ] **Step 5: Commit**

```bash
git add prefab-gate/scripts/gate/kicad.py prefab-gate/tests/test_kicad_drc.py
git commit -m "feat(prefab-gate): run DRC with parity and zone refill, parse JSON"
```

---

### Task 6: Render the verdict

**Files:**
- Create: `prefab-gate/scripts/gate/report.py`
- Test: `prefab-gate/tests/test_report.py`

**Interfaces:**
- Consumes: `Verdict`, `Finding` from Task 1
- Produces: `render_text(verdict) -> str`; `render_json(verdict) -> str`

The report is a first-class output, not a debug aid: a blocked run must say what blocked it and where, without the user opening KiCad.

- [ ] **Step 1: Write the failing test**

```python
import json
import unittest
from gate.model import Finding, Verdict
from gate.report import render_text, render_json

def f(blocking, description="Courtyards overlap", items=("Footprint TP1", "Footprint J3")):
    return Finding(kind="violation", type="courtyards_overlap", description=description,
                   severity="error" if blocking else "warning", items=items,
                   blocking=blocking, reason="DRC severity is error")

class TestRenderText(unittest.TestCase):
    def test_blocked_report_names_the_blocking_finding_and_its_items(self):
        text = render_text(Verdict(blocking=[f(True)], cosmetic=[]))
        self.assertIn("BLOCKED", text)
        self.assertIn("Courtyards overlap", text)
        self.assertIn("Footprint TP1", text)

    def test_clean_report_says_so_and_counts_what_it_waved_through(self):
        text = render_text(Verdict(blocking=[], cosmetic=[f(False), f(False)]))
        self.assertIn("PASSED", text)
        self.assertIn("2", text)

    def test_cosmetic_findings_are_listed_not_just_counted(self):
        text = render_text(Verdict(blocking=[], cosmetic=[f(False, "Silkscreen clipped")]))
        self.assertIn("Silkscreen clipped", text)

class TestRenderJson(unittest.TestCase):
    def test_json_is_machine_readable_and_carries_both_classes(self):
        data = json.loads(render_json(Verdict(blocking=[f(True)], cosmetic=[f(False)])))
        self.assertIs(data["passed"], False)
        self.assertEqual(len(data["blocking"]), 1)
        self.assertEqual(len(data["cosmetic"]), 1)
        self.assertEqual(data["blocking"][0]["type"], "courtyards_overlap")
```

- [ ] **Step 2: Run test to verify it fails**

Run: `cd prefab-gate/scripts && python3 -m unittest tests.test_report -v`
Expected: FAIL with `ModuleNotFoundError: No module named 'gate.report'`

- [ ] **Step 3: Write minimal implementation**

```python
"""Human and machine renderings of a verdict."""
import json
from dataclasses import asdict

def _line(finding):
    where = f"  [{', '.join(finding.items)}]" if finding.items else ""
    return (f"  {finding.type or finding.kind:32} {finding.description}{where}\n"
            f"      {finding.reason}")

def render_text(verdict) -> str:
    out = []
    if verdict.passed:
        out.append(f"PASSED — nothing blocking. {len(verdict.cosmetic)} cosmetic "
                   f"finding(s) waved through.")
    else:
        out.append(f"BLOCKED — {len(verdict.blocking)} blocking finding(s). "
                   "No files were produced.")
        out.append("")
        out.append("Blocking:")
        out.extend(_line(f) for f in verdict.blocking)
    if verdict.cosmetic:
        out.append("")
        out.append(f"Cosmetic ({len(verdict.cosmetic)}):")
        out.extend(_line(f) for f in verdict.cosmetic)
    return "\n".join(out)

def render_json(verdict) -> str:
    return json.dumps({
        "passed": verdict.passed,
        "blocking": [asdict(f) for f in verdict.blocking],
        "cosmetic": [asdict(f) for f in verdict.cosmetic],
    }, indent=2)
```

- [ ] **Step 4: Run test to verify it passes**

Run: `cd prefab-gate/scripts && python3 -m unittest tests.test_report -v`
Expected: 4 tests PASS

- [ ] **Step 5: Commit**

```bash
git add prefab-gate/scripts/gate/report.py prefab-gate/tests/test_report.py
git commit -m "feat(prefab-gate): render verdicts as text and JSON"
```

---

### Task 7: Build the manifest

**Files:**
- Create: `prefab-gate/scripts/gate/manifest.py`
- Test: `prefab-gate/tests/test_manifest.py`

**Interfaces:**
- Consumes: `Verdict` from Task 1
- Produces: `sha256(path) -> str`; `build_manifest(board, cli_version, verdict, files) -> dict`

- [ ] **Step 1: Write the failing test**

```python
import os
import tempfile
import unittest
from gate.model import Finding, Verdict
from gate.manifest import sha256, build_manifest

class TestManifest(unittest.TestCase):
    def setUp(self):
        self.tmp = tempfile.TemporaryDirectory()
        self.board = os.path.join(self.tmp.name, "b.kicad_pcb")
        with open(self.board, "w") as fh:
            fh.write("(kicad_pcb)")
        self.addCleanup(self.tmp.cleanup)

    def test_sha256_is_stable_and_content_dependent(self):
        first = sha256(self.board)
        self.assertEqual(first, sha256(self.board))
        with open(self.board, "a") as fh:
            fh.write(" ")
        self.assertNotEqual(first, sha256(self.board))

    def test_manifest_records_board_hash_and_cli_version(self):
        m = build_manifest(self.board, "10.0.5", Verdict(), [])
        self.assertEqual(m["board"]["sha256"], sha256(self.board))
        self.assertEqual(m["kicad_cli_version"], "10.0.5")

    def test_manifest_records_every_cosmetic_finding_it_let_past(self):
        waved = Finding(kind="violation", type="silk_overlap", description="Silk",
                        severity="warning", items=(), blocking=False, reason="warning")
        m = build_manifest(self.board, "10.0.5", Verdict(cosmetic=[waved]), [])
        self.assertEqual(len(m["verdict"]["cosmetic"]), 1)
        self.assertEqual(m["verdict"]["cosmetic"][0]["type"], "silk_overlap")

    def test_manifest_checksums_each_exported_file(self):
        m = build_manifest(self.board, "10.0.5", Verdict(), [self.board])
        self.assertEqual(m["files"][0]["sha256"], sha256(self.board))
```

- [ ] **Step 2: Run test to verify it fails**

Run: `cd prefab-gate/scripts && python3 -m unittest tests.test_manifest -v`
Expected: FAIL with `ModuleNotFoundError: No module named 'gate.manifest'`

- [ ] **Step 3: Write minimal implementation**

```python
"""The package receipt.

Answers, months later: what was sent, from which board state, and what did the
gate knowingly allow past?
"""
import hashlib
import os
from dataclasses import asdict
from datetime import datetime, timezone

def sha256(path: str) -> str:
    digest = hashlib.sha256()
    with open(path, "rb") as fh:
        for chunk in iter(lambda: fh.read(65536), b""):
            digest.update(chunk)
    return digest.hexdigest()

def build_manifest(board: str, cli_version: str, verdict, files) -> dict:
    return {
        "generated": datetime.now(timezone.utc).isoformat(),
        "kicad_cli_version": cli_version,
        "board": {"path": os.path.basename(board), "sha256": sha256(board)},
        "verdict": {
            "passed": verdict.passed,
            "blocking": [asdict(f) for f in verdict.blocking],
            "cosmetic": [asdict(f) for f in verdict.cosmetic],
        },
        "files": [{"name": os.path.basename(p), "sha256": sha256(p)} for p in sorted(files)],
    }
```

- [ ] **Step 4: Run test to verify it passes**

Run: `cd prefab-gate/scripts && python3 -m unittest tests.test_manifest -v`
Expected: 4 tests PASS

- [ ] **Step 5: Commit**

```bash
git add prefab-gate/scripts/gate/manifest.py prefab-gate/tests/test_manifest.py
git commit -m "feat(prefab-gate): build a package manifest with hashes and waived findings"
```

---

### Task 8: Export the package atomically

**Files:**
- Create: `prefab-gate/scripts/gate/export.py`
- Test: `prefab-gate/tests/test_export.py`

**Interfaces:**
- Consumes: `KicadUnavailable` from Task 4
- Produces: `schematic_for(board) -> str`; `export_package(cli, board, out_dir, runner=subprocess.run) -> str` returning the final package directory path

Four kicad-cli invocations: `pcb export gerbers --board-plot-params` (honours the board's own layer setup), `pcb export drill`, `pcb export pos --format csv`, and `sch export bom` against the sibling schematic — the BOM comes from the schematic because that is where sourcing fields live.

- [ ] **Step 1: Write the failing test**

```python
import os
import tempfile
import unittest
from gate.export import export_package, schematic_for

class TestSchematicFor(unittest.TestCase):
    def test_swaps_the_extension(self):
        self.assertEqual(schematic_for("/p/board.kicad_pcb"), "/p/board.kicad_sch")

class TestExport(unittest.TestCase):
    def setUp(self):
        self.tmp = tempfile.TemporaryDirectory()
        self.addCleanup(self.tmp.cleanup)
        self.board = os.path.join(self.tmp.name, "b.kicad_pcb")
        for path in (self.board, os.path.join(self.tmp.name, "b.kicad_sch")):
            with open(path, "w") as fh:
                fh.write("x")
        self.calls = []

    def runner(self, fail_on=None):
        def _run(cmd, **kwargs):
            self.calls.append(cmd)
            class R:
                pass
            r = R()
            r.returncode = 1 if fail_on and fail_on in " ".join(cmd) else 0
            r.stdout = r.stderr = ""
            if r.returncode == 0 and "-o" in cmd:
                target = cmd[cmd.index("-o") + 1]
                if target.endswith(".csv"):
                    os.makedirs(os.path.dirname(target), exist_ok=True)
                    open(target, "w").close()
                else:
                    os.makedirs(target, exist_ok=True)
                    open(os.path.join(target, "plot.gbr"), "w").close()
            return r
        return _run

    def test_produces_a_timestamped_directory(self):
        out = os.path.join(self.tmp.name, "fab")
        package = export_package("kicad-cli", self.board, out, runner=self.runner())
        self.assertTrue(os.path.isdir(package))
        self.assertTrue(package.startswith(out))

    def test_runs_gerbers_drill_pos_and_bom(self):
        export_package("kicad-cli", self.board, os.path.join(self.tmp.name, "fab"),
                       runner=self.runner())
        joined = [" ".join(c) for c in self.calls]
        self.assertTrue(any("export gerbers" in c for c in joined))
        self.assertTrue(any("export drill" in c for c in joined))
        self.assertTrue(any("export pos" in c for c in joined))
        self.assertTrue(any("sch export bom" in c for c in joined))

    def test_a_failure_leaves_no_package_behind(self):
        out = os.path.join(self.tmp.name, "fab")
        with self.assertRaises(Exception):
            export_package("kicad-cli", self.board, out, runner=self.runner(fail_on="drill"))
        self.assertEqual([] if not os.path.isdir(out) else os.listdir(out), [])
```

- [ ] **Step 2: Run test to verify it fails**

Run: `cd prefab-gate/scripts && python3 -m unittest tests.test_export -v`
Expected: FAIL with `ModuleNotFoundError: No module named 'gate.export'`

- [ ] **Step 3: Write minimal implementation**

```python
"""Atomic fab-package export.

Built in a temp directory and moved into place only on success, so a failure
never leaves something that looks shippable.
"""
import os
import shutil
import subprocess
import tempfile
from datetime import datetime

from gate.kicad import KicadUnavailable

def schematic_for(board: str) -> str:
    return os.path.splitext(board)[0] + ".kicad_sch"

def _run(runner, cmd):
    result = runner(cmd, capture_output=True, text=True)
    if getattr(result, "returncode", 0) != 0:
        raise KicadUnavailable(
            f"{' '.join(cmd[1:4])} failed (exit {result.returncode}): "
            f"{(getattr(result, 'stderr', '') or '').strip()}")

def export_package(cli: str, board: str, out_dir: str, runner=subprocess.run) -> str:
    stamp = datetime.now().strftime("%Y-%m-%d-%H-%M-%S")
    final = os.path.join(out_dir, stamp)
    staging = tempfile.mkdtemp(prefix=".prefab-gate-")
    try:
        _run(runner, [cli, "pcb", "export", "gerbers", "--board-plot-params",
                      "-o", os.path.join(staging, "gerbers"), board])
        _run(runner, [cli, "pcb", "export", "drill", "--format", "excellon",
                      "--excellon-units", "mm", "--generate-map",
                      "-o", os.path.join(staging, "drill"), board])
        _run(runner, [cli, "pcb", "export", "pos", "--format", "csv", "--units", "mm",
                      "--side", "both", "-o", os.path.join(staging, "cpl.csv"), board])
        _run(runner, [cli, "sch", "export", "bom", "--group-by", "",
                      "--fields", "Reference,Value,Footprint,Manufacturer,MPN,LCSC,Datasheet",
                      "-o", os.path.join(staging, "bom.csv"), schematic_for(board)])
        os.makedirs(out_dir, exist_ok=True)
        shutil.move(staging, final)
        return final
    except BaseException:
        shutil.rmtree(staging, ignore_errors=True)
        raise
```

- [ ] **Step 4: Run test to verify it passes**

Run: `cd prefab-gate/scripts && python3 -m unittest tests.test_export -v`
Expected: 4 tests PASS

- [ ] **Step 5: Commit**

```bash
git add prefab-gate/scripts/gate/export.py prefab-gate/tests/test_export.py
git commit -m "feat(prefab-gate): export gerbers, drill, CPL and BOM atomically"
```

---

### Task 9: Wire the CLI

**Files:**
- Create: `prefab-gate/scripts/prefab_gate.py`
- Test: `prefab-gate/tests/test_cli.py`

**Interfaces:**
- Consumes: everything above
- Produces: `main(argv, deps=None) -> int`. `deps` is a dict overriding `locate_cli`, `probe_capability`, `run_drc`, `export_package`, `cli_version` for tests

- [ ] **Step 1: Write the failing test**

```python
import io
import unittest
from contextlib import redirect_stdout
from prefab_gate import main

CLEAN = {"violations": [], "unconnected_items": [], "schematic_parity": []}
BLOCKED = {"violations": [{"type": "courtyards_overlap", "description": "Courtyards overlap",
                           "severity": "error", "items": [{"description": "Footprint TP1"}]}],
           "unconnected_items": [], "schematic_parity": []}

def deps(drc, exported=None, record=None):
    def export(*args, **kwargs):
        if record is not None:
            record.append(args)
        return "/fab/2026-01-01-00-00-00"
    return {"locate_cli": lambda: "kicad-cli", "probe_capability": lambda cli: None,
            "run_drc": lambda cli, board: drc, "export_package": export,
            "cli_version": lambda cli: "10.0.5"}

class TestCli(unittest.TestCase):
    def test_check_on_a_clean_board_exits_zero(self):
        with redirect_stdout(io.StringIO()) as out:
            code = main(["check", "b.kicad_pcb"], deps=deps(CLEAN))
        self.assertEqual(code, 0)
        self.assertIn("PASSED", out.getvalue())

    def test_check_on_a_blocked_board_exits_two(self):
        with redirect_stdout(io.StringIO()) as out:
            code = main(["check", "b.kicad_pcb"], deps=deps(BLOCKED))
        self.assertEqual(code, 2)
        self.assertIn("BLOCKED", out.getvalue())

    def test_package_does_not_export_when_blocked(self):
        record = []
        with redirect_stdout(io.StringIO()):
            code = main(["package", "b.kicad_pcb"], deps=deps(BLOCKED, record=record))
        self.assertEqual(code, 2)
        self.assertEqual(record, [])

    def test_package_exports_when_clean(self):
        record = []
        with redirect_stdout(io.StringIO()) as out:
            code = main(["package", "b.kicad_pcb"], deps=deps(CLEAN, record=record))
        self.assertEqual(code, 0)
        self.assertEqual(len(record), 1)
        self.assertIn("2026-01-01-00-00-00", out.getvalue())

    def test_missing_kicad_cli_exits_three(self):
        from gate.kicad import KicadUnavailable

        def boom():
            raise KicadUnavailable("kicad-cli not found")
        d = deps(CLEAN)
        d["locate_cli"] = boom
        with redirect_stdout(io.StringIO()) as out:
            code = main(["check", "b.kicad_pcb"], deps=d)
        self.assertEqual(code, 3)
        self.assertIn("kicad-cli not found", out.getvalue())

    def test_json_flag_emits_machine_readable_output(self):
        import json
        with redirect_stdout(io.StringIO()) as out:
            main(["check", "b.kicad_pcb", "--json"], deps=deps(CLEAN))
        self.assertIs(json.loads(out.getvalue().split("\n\n")[-1])["passed"], True)

    def test_says_so_when_the_refill_modified_the_board(self):
        d = deps(CLEAN)
        hashes = iter(["before", "after"])
        d["board_hash"] = lambda path: next(hashes)
        with redirect_stdout(io.StringIO()) as out:
            main(["check", "b.kicad_pcb"], deps=d)
        self.assertIn("zone fills", out.getvalue())

    def test_stays_quiet_when_the_board_was_already_filled(self):
        d = deps(CLEAN)
        d["board_hash"] = lambda path: "same"
        with redirect_stdout(io.StringIO()) as out:
            main(["check", "b.kicad_pcb"], deps=d)
        self.assertNotIn("zone fills", out.getvalue())
```

The `deps()` helper above must also supply `"board_hash": lambda path: "same"` by
default, so tests that do not care about refilling stay quiet.

- [ ] **Step 2: Run test to verify it fails**

Run: `cd prefab-gate/scripts && python3 -m unittest tests.test_cli -v`
Expected: FAIL with `ModuleNotFoundError: No module named 'prefab_gate'`

- [ ] **Step 3: Write minimal implementation**

```python
#!/usr/bin/env python3
"""Pre-fab gate: no fab package without a passing check."""
import argparse
import json
import os
import subprocess
import sys

sys.path.insert(0, os.path.dirname(os.path.abspath(__file__)))

from gate.classify import classify                      # noqa: E402
from gate.export import export_package                  # noqa: E402
from gate.kicad import KicadUnavailable, locate_cli, probe_capability, run_drc  # noqa: E402
from gate.manifest import build_manifest, sha256        # noqa: E402
from gate.report import render_json, render_text        # noqa: E402

def _cli_version(cli):
    result = subprocess.run([cli, "version"], capture_output=True, text=True)
    return (result.stdout or "").strip()

DEFAULT_DEPS = {"locate_cli": locate_cli, "probe_capability": probe_capability,
                "run_drc": run_drc, "export_package": export_package,
                "cli_version": _cli_version, "board_hash": sha256}

def main(argv=None, deps=None) -> int:
    d = dict(DEFAULT_DEPS)
    d.update(deps or {})

    parser = argparse.ArgumentParser(prog="prefab_gate", description=__doc__)
    sub = parser.add_subparsers(dest="command", required=True)
    for name in ("check", "package"):
        p = sub.add_parser(name)
        p.add_argument("board")
        p.add_argument("--out", default="fab")
        p.add_argument("--json", action="store_true")
        p.add_argument("--strict", action="store_true")
    args = parser.parse_args(argv)

    try:
        cli = d["locate_cli"]()
        d["probe_capability"](cli)
        # --refill-zones --save-board can rewrite the board. Hash it either side so
        # the resulting git diff is expected rather than mysterious.
        before = d["board_hash"](args.board)
        drc = d["run_drc"](cli, args.board)
        if d["board_hash"](args.board) != before:
            print(f"Note: refilling updated the zone fills in {args.board} — "
                  "the board file has been modified and should be committed.\n")
    except KicadUnavailable as exc:
        print(str(exc))
        return 3

    verdict = classify(drc, strict=args.strict)
    print(render_text(verdict))

    code = 0 if verdict.passed else 2
    if verdict.passed and args.command == "package":
        try:
            package = d["export_package"](cli, args.board, args.out)
        except KicadUnavailable as exc:
            print(str(exc))
            return 3
        files = [os.path.join(root, f) for root, _, fs in os.walk(package) for f in fs]
        manifest = build_manifest(args.board, d["cli_version"](cli), verdict, files)
        with open(os.path.join(package, "manifest.json"), "w") as fh:
            json.dump(manifest, fh, indent=2)
        print(f"\nPackage written to {package}")

    if args.json:
        print()
        print(render_json(verdict))
    return code

if __name__ == "__main__":
    raise SystemExit(main())
```

- [ ] **Step 4: Run test to verify it passes**

Run: `cd prefab-gate/scripts && python3 -m unittest discover -s ../tests -t . -v`
Expected: all tests PASS

- [ ] **Step 5: Commit**

```bash
git add prefab-gate/scripts/prefab_gate.py prefab-gate/tests/test_cli.py
git commit -m "feat(prefab-gate): wire check and package subcommands"
```

---

### Task 10: Package as a plugin and verify against the real board

**Files:**
- Create: `prefab-gate/plugin.json`
- Create: `prefab-gate/skills/prefab-gate/SKILL.md`
- Create: `prefab-gate/README.md`

**Interfaces:**
- Consumes: the CLI from Task 9
- Produces: an installable plugin directory

- [ ] **Step 1: Write plugin.json**

```json
{
  "name": "prefab-gate",
  "version": "0.1.0",
  "description": "Refuses to produce a KiCad fab package from a board that has not passed verification. Runs DRC with zone refill and schematic parity, classifies findings as blocking or cosmetic, and exports gerbers, drill, CPL and BOM only when nothing blocks.",
  "license": "MIT",
  "keywords": ["kicad", "pcb", "drc", "fabrication", "gerber", "hardware"]
}
```

- [ ] **Step 2: Write SKILL.md**

```markdown
---
name: prefab-gate
description: Use before ordering any KiCad PCB - verifies a board with DRC, zone refill and schematic parity, and refuses to export a fab package if anything blocking is found. Triggers on "order this board", "generate gerbers", "fab package", "is this ready to fab", "send to JLCPCB/PCBWay".
---

# Pre-fab gate

Never hand-generate gerbers. Run:

    python3 scripts/prefab_gate.py package <board.kicad_pcb>

Exit codes: `0` clean and packaged · `2` blocked, no files written · `3` kicad-cli missing or too old.

Use `check` instead of `package` to verify without producing files.

## Reading a verdict

Blocking findings stop the export. Cosmetic ones are listed, waved through, and
recorded in the package manifest so you can see later what shipped despite them.

An **unrecognised parity description always blocks** — if you see one, it means
KiCad reworded a message and the classifier needs the new string added. Do not
work around it by exporting by hand.

## What it does not do

It does not replace design review. It checks that the board you have is
internally consistent and manufacturable, not that it is the board you meant.
```

- [ ] **Step 3: Run the full unit suite**

Run: `cd prefab-gate/scripts && python3 -m unittest discover -s ../tests -t . -v`
Expected: all tests PASS

- [ ] **Step 4: Run against the real board and check the acceptance verdict**

Run: `cd prefab-gate/scripts && python3 prefab_gate.py check ../../nes_power_video.kicad_pcb`

Expected — exit code `2`, and exactly these two blocking findings:

```
BLOCK  courtyards_overlap         Footprint TP1, Footprint J3
BLOCK  footprint_symbol_mismatch  Footprint J5
```

with 33 cosmetic: 4 `silk_edge_clearance`, 2 `silk_overlap`, 23 `footprint_symbol_field_mismatch`, and 4 exclude-from-BOM differences on TP1–TP4. (This plan and the spec both said 29 while their own breakdown summed to 33; 33 is correct and has been verified twice against the board.)

**If the verdict differs, the gate is wrong — stop and investigate before adjusting the expectation.** The counts come from a real DRC run on this board at commit `c37b56b`.

- [ ] **Step 5: Commit**

```bash
git add .claude-plugin prefab-gate/.claude-plugin prefab-gate/skills prefab-gate/README.md
git commit -m "feat(prefab-gate): package as an installable plugin"
```

---

## Notes for the executor

- `sys.path` juggling in `prefab_gate.py` is deliberate: the plugin has to run as a bare script with no installation step, so `gate/` is imported relative to the script's own directory.
- Tests run from `prefab-gate/scripts` so that `gate` and `prefab_gate` are both importable without packaging.
- Do not add pytest. `unittest` is in the standard library; the plugin's whole distribution story depends on having no dependencies.

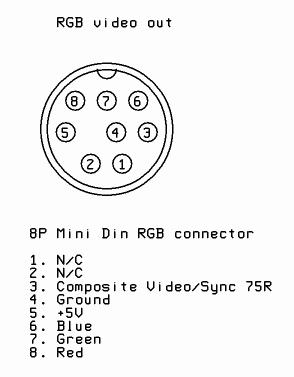
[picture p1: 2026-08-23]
rgbpinout.png

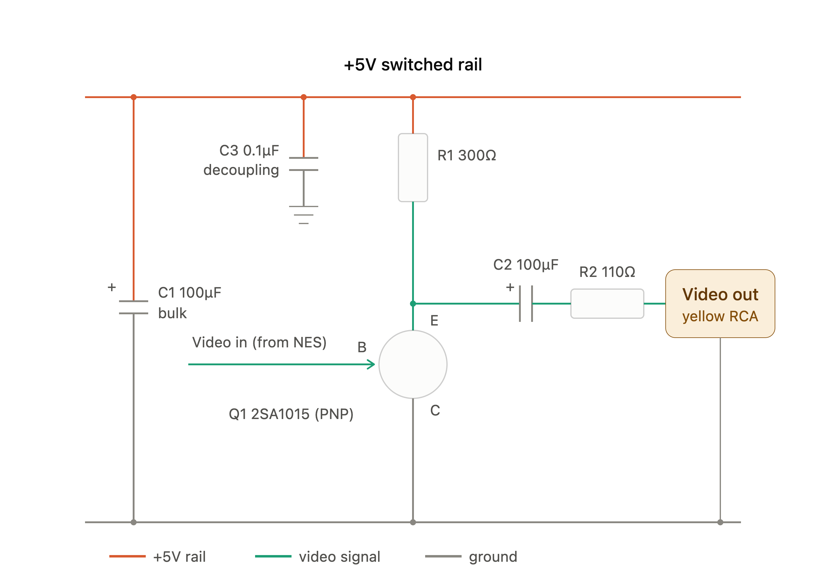
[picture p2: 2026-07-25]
nes_video_amp_final_schematic.png

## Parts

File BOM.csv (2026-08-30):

Reference | Description | Value | Package/Footprint | Manufacturer | Manufacturer Part Number | LCSC | Datasheet | Quantity | Supplier Link | Notes
C1 | Electrolytic capacitor | 100µF 16V | Radial THT | Generic |  |  |  | 1 |  | Bulk cap on switched 5V rail to GND. Spec: 100 uF, >=16 V, aluminium electrolytic, radial, <=10 mm dia, 5.0 mm pitch. No MPN - any equivalent.
C2 | Electrolytic capacitor | 470µF 16V | Radial THT | Generic |  |  |  | 1 |  | Coupling cap; blocks DC bias from Q1 emitter before RCA jack. 470µF not 100µF: into the 150Ω load (R5 75Ω + TV 75Ω) 100µF gives τ=15ms against the 16.7ms field period, which tilts the picture top-to-bottom. 470µF gives τ=70ms. Spec: 470 uF, >=16 V, aluminium electrolytic, radial, <=10 mm dia, 5.0 mm pitch. No MPN - any equivalent.
C3 | Ceramic capacitor | 100nF | 0805 SMD | YAGEO | CC0805KRX7R9BB104 | C49678 | https://www.lcsc.com/datasheet/C49678.pdf | 1 | https://www.lcsc.com/product-detail/C49678.html | X7R 16V+; U1 input decoupling - mount as close to U1 pin 1 as possible (TI datasheet requirement). Spec: 100 nF +/-10%, >=16 V, X7R, 0805 - any equivalent; the LCSC part above is a JLCPCB basic part.
D1 | TVS diode (1500W unidirectional) | 1.5KE6.8A | DO-201AE THT | Littelfuse | 1.5KE6.8A |  | https://www.littelfuse.com/assetdocs/littelfuse_tvs_diode_1_5ke_datasheet.pdf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 | 1 | https://www.digikey.com/en/products/detail/littelfuse-inc/1-5KE6-8A/285842 | VWM 5.80V / VBR 6.45-7.14V @10mA / VC 10.5V @144.8A (Littelfuse figures; the part actually fitted). Vishay's equivalent is 1.5KE6.8A-E3/54 - the plain 1.5KE6.8A MPN is Littelfuse's. Littelfuse packages it DO-201AA/DO-27 rather than DO-201AE; the 15.24 mm footprint takes either. Cathode (banded end) toward +5V - the KiCad symbol names both pins A1/A2 and shows no polarity, but the footprint silkscreen has the band. Clamps above U1 absolute max 7V, so it protects the NES, not the eFuse.
F1 | PTC resettable polyfuse | 2A (IH=2.0A / IT=3.8A / VMAX=16V) | Radial disc THT | Littelfuse | RHEF200 |  | https://www.littelfuse.com/assetdocs/resettable-ptc-rhef-datasheet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 | 1 | https://www.digikey.com/en/products/detail/littelfuse-inc/RHEF200/5130265 | Non-polarized; backup protection upstream of U1 eFuse. KiCad footprint field mislabeled as polarized cap footprint in v1 (fix in v2). Footprint: no KiCad footprint exists for the Littelfuse RHEF series. F1 uses Fuse:Fuse_Bourns_MF-RG300 - pads 5.24 mm centre-to-centre, 1.01 mm drills. The RHEF200's 0.51 mm leads at 5.05 +/-0.75 mm spacing fit that, but the Bourns part is a 3.0 A/5.1 A device and the silkscreen outline is its body, not the RHEF200's - don't use it for clearance.
J2 | RCA phono jack, right-angle PCB mount (audio) | Audio | Right-angle THT, Switchcraft PJRA series | Switchcraft | PJRAN1X1U03X |  | https://www.switchcraft.com/assets/1/24/PJRAN1X1U__X_SERIES_CD.PDF | 1 | https://www.mouser.com/en/ProductDetail/Switchcraft/PJRAN1X1U03X?qs=mcPJWgAPNrc45bmxqO8nXw%3D%3D | Audio pass-through from J4 pin 2 - the board does not amplify audio. Sleeve to GND. Mouser 502-PJRAN1X1U03X. Red-bodied part; order the colour you want.
J3 | RCA phono jack, right-angle PCB mount (video) | Video | Right-angle THT, Switchcraft PJRA series | Switchcraft | PJRAN1X1U03X |  | https://www.switchcraft.com/assets/1/24/PJRAN1X1U__X_SERIES_CD.PDF | 1 | https://www.mouser.com/en/ProductDetail/Switchcraft/PJRAN1X1U03X?qs=mcPJWgAPNrc45bmxqO8nXw%3D%3D | Composite video output, fed from C2 through R5. Sleeve to GND - see the v1 fault where this sleeve was wired to the audio net.
J4 | Pin header 1x05, feed from the NES | Conn_01x05 | 2.54mm THT vertical | Generic |  |  |  | 1 |  | Connection to the console: 1=video in, 2=audio in, 3=+5V out to the NES, 4/5=GND. Was missing from this BOM until 2026-08-28. Spec: 1x05 pin header, 2.54 mm, vertical THT. Suggested: LCSC C492404 (PZ254V-11-05P).
J5 | Pin header 1x03 | RGB conn feed | 2.54mm THT vertical | Generic |  |  |  | 1 |  | Feed to the panel-mounted 8-pin mini-DIN RGB connector: 1=video/sync, 2=GND, 3=+5V. Connector itself ships with the NESRGB kit and mounts in the shell. Spec: 1x03 pin header, 2.54 mm, vertical THT. Suggested: LCSC C2937625 (PZ254V-11-03P).
Q1 | PNP transistor | 2SA733 | TO-92 THT | UTC (Unisonic) | 2SA733L-P-T92-B | C5310429 | https://www.unisonic.com.tw/uploadfiles/836/part_no_pdf/2SA733.pdf | 1 | https://www.lcsc.com/product-detail/C5310429.html | Flat side facing viewer, leads down = E-C-B left to right. Base=video in (through R2), Emitter=R1/C2 node, Collector=GND. Replaces the 2SA1015/KSA1015, which are both End of Life (checked 2026-08-29): MCC 2SA1015-GR-AP is stocked at Mouser but EOL, and every onsemi KSA1015 reads Obsolete on DigiKey, available only through Rochester. The 2SA733 is in production, shares the E-C-B pin order exactly, and is a better part for a video buffer: fT 190 MHz typ vs 80 MHz, Cob 2-3 pF, PC 750 mW, same VCEO -50 V / IC -150 mA / VEBO -5 V. Rank P is hFE 200-400, which matches the ~46 uA base current measured on the bench, so the bias point does not move. DigiKey's Renesas 2SA733 is Rochester stock at $1.90 - buy the UTC part from LCSC at $0.035 instead. Do NOT substitute a 2N3906 or BC557 on this board: both are electrically fine here but put the BASE in the middle pin where this footprint wants the COLLECTOR, and no rotation fixes that. Pin order is a manufacturer's choice - check the datasheet of the brand you actually buy.
R1 | Resistor | 220Ω | THT | Generic |  |  |  | 1 |  | Q1 emitter load: one end +5V, other end to Q1 emitter/C2 node. Not both ends to +5V. Lowered from 300Ω for v2 to raise the drive current: at the assumed ~1.3V base, 300-330Ω supplies only ~6.2mA at peak white against the ~6.7mA the 150Ω load needs. 220Ω gives ~9.3mA and real headroom. Retune if the measured DC at J4.1 differs from ~1.3V. Spec: 220 ohm +/-5%, >=0.25 W, axial THT 7.62 mm pitch. No MPN - any equivalent.
R2 | Resistor | 330Ω | Axial THT DIN0207 P7.62mm | Generic |  |  |  | 1 |  | Series resistor between J4.1 (video in from NES) and Q1's base. Mirrors the 330Ω Nintendo places in the same position. Negligible signal loss against Q1's ~21kΩ base input impedance; limits fault current into the base-emitter junction, whose reverse rating is only 5V. New in v2. Spec: 330 ohm +/-5%, >=0.25 W, axial THT 7.62 mm pitch. No MPN - any equivalent.
R3 | Resistor | 5.1kΩ | THT | Generic |  |  |  | 1 |  | CC1 pulldown; measured 5.07kΩ. Spec: 5.1 kohm +/-5%, >=0.1 W, axial THT 7.62 mm pitch. No MPN - any equivalent.
R4 | Resistor | 5.1kΩ | THT | Generic |  |  |  | 1 |  | CC2 pulldown; measured 5.13kΩ. Spec: 5.1 kohm +/-5%, >=0.1 W, axial THT 7.62 mm pitch. No MPN - any equivalent.
R5 | Resistor | 75Ω | THT | Generic |  |  |  | 1 |  | Video series termination; populated on the fabbed v1 board. Spec: 75 ohm +/-1%, >=0.25 W, axial THT 7.62 mm pitch. No MPN - any equivalent.
R6 | Resistor | 22k | 0805 SMD | UNI-ROYAL | 0805W8F2202T5E | C17560 | https://www.lcsc.com/datasheet/C17560.pdf | 1 | https://www.lcsc.com/product-detail/C17560.html | Sets U1 current limit. I_OS = 25.9/R_ILIM(kohm) -> ~1.18A typ. Higher R = LOWER limit. Valid range 15k-232k. Spec: 22 kohm +/-1%, 0805 - keep the 1% tolerance, it sets the current limit. JLCPCB basic part.
R7 | Resistor | 75 Ohm | Axial THT DIN0207 P7.62mm | Generic |  |  |  | 1 |  | Series source termination for the mini-DIN RGB connector video pin (mirrors R5 for the RCA jack). Spec: 75 ohm +/-1%, >=0.25 W, axial THT 7.62 mm pitch. No MPN - any equivalent.
TP1-TP4 | Test point (through-hole pad) |  | 2.0mm pad / 1.0mm drill THT | Not a purchased part |  |  |  | 4 |  | Not a purchased part — bare plated holes for bring-up (video, GND, +5V, audio). Optionally fit 0.64mm square header pins for scope grabbers.
U1 | Current-limited power switch (eFuse) | TPS2553DBVR | SOT-23-6 SMD | Texas Instruments | TPS2553DBVR | C55266 | https://www.ti.com/lit/ds/symlink/tps2553.pdf | 1 | https://www.lcsc.com/product-detail/C55266.html | Adjustable OCP between F1 and the 5V rail. EN (pin 3) active-high tied to IN. Auto-retry version (the -1 suffix is latch-off). FAULT (pin 4) left unconnected
USB-C1 | USB-C receptacle | USB4970-00-A | SMD | GCT | USB4970-00-A |  | https://gct.co/files/drawings/usb4970.pdf | 1 | https://www.digikey.com/en/products/detail/gct/USB4970-00-A/28722813 | 6-pin power-only (VBUS x2, GND x2, CC1, CC2); no data lines. Footprint: no KiCad USB4970 footprint exists. GCT's USB4970 drawing gives the same recommended land pattern as the USB4125 (pad centres 1.00/3.04/5.50 mm, shell holes 8.64 x 3.80 mm), verified 2026-08-28, so Connector_USB:USB_C_Receptacle_GCT_USB4125-xx-x is correct. Use the plain variant, not -0190: USB4970-00-A takes the 1.00 mm shell stake, -0190 is the 1.90 mm one.

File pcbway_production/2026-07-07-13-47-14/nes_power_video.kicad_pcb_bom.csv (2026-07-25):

Designator | Quantity | Value | Footprint | Package | MPN | DNP | Mount_Type | Description | KiLib_Generator | Sim.Device | Sim.Pins
C1, C2 | 2 | 100uf | CP_Radial_D10.0mm_P5.00mm |  |  |  | tht | Polarized capacitor | capacitor/THT/other
D1 | 1 | 1.5KExxA | D_DO-201AE_P15.24mm_Horizontal |  |  |  | tht | 1500W unidirectional TVS diode, DO-201AE | diode/THT
F1 | 1 | Polyfuse_Small | Fuse_Bourns_MF-RG300 |  |  |  | tht | Resettable fuse, polymeric positive temperature coefficient, small symbol | fuse
J2 | 1 | Audio | nes connector |  |  |  | tht | RCA Jack Through Hole
J3 | 1 | Video | nes connector |  |  |  | tht | RCA Jack Through Hole
J4 | 1 | Conn_01x05 | PinHeader_1x05_P2.54mm_Vertical |  |  |  | tht | Generic connector, single row, 01x05, script generated (kicad-library-utils/schlib/autogen/connector/) | connector/pin_header_socket
Q1 | 1 | 2SA1015 | TO-92_Inline |  |  |  | tht | -0.15A Ic, -50V Vce, Low Noise Audio PNP Transistor, TO-92 |  | PNP | 1=E 2=C 3=B
R1 | 1 | 300 | R_Axial_DIN0207_L6.3mm_D2.5mm_P7.62mm_Horizontal |  |  |  | tht | Resistor, small symbol | resistor/THT
R3, R4 | 2 | 5.1k | R_Axial_DIN0207_L6.3mm_D2.5mm_P7.62mm_Horizontal |  |  |  | tht | Resistor | resistor/THT
R5 | 1 | 75 Ohm | R_Axial_DIN0207_L6.3mm_D2.5mm_P7.62mm_Horizontal |  |  |  | tht | Resistor | resistor/THT
USB-C1 | 1 | USB_C_Receptacle_PowerOnly_6P | USB_C_Receptacle_GCT_USB4125-xx-x-0190_6P_TopMnt_Horizontal |  |  |  | smt | USB Power-Only 6P Type-C Receptacle connector

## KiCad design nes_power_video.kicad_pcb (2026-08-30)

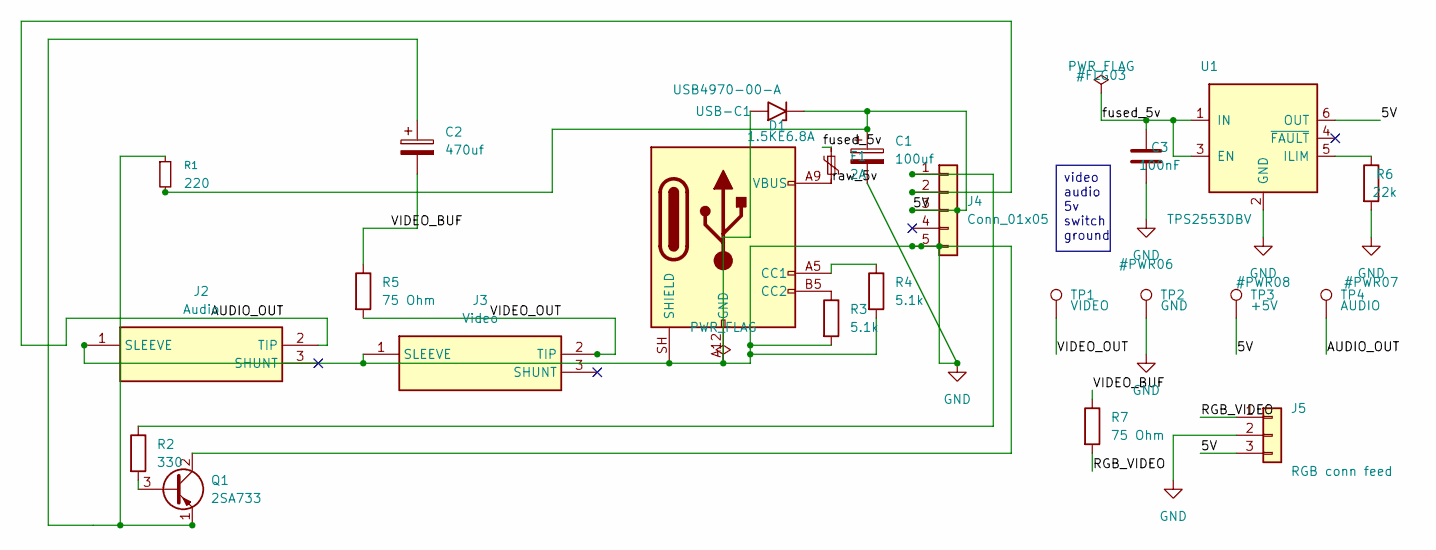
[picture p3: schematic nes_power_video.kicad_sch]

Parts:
C1: 100uf; CP_Radial_D10.0mm_P5.00mm
C2: 470uf; CP_Radial_D10.0mm_P5.00mm
C3: 100nF; C_0805_2012Metric_Pad1.18x1.45mm_HandSolder; MPN CC0805KRX7R9BB104; LCSC C49678
D1: 1.5KE6.8A; D_DO-201AE_P15.24mm_Horizontal; MPN 1.5KE6.8A
F1: 2A; Fuse_Bourns_MF-RG300; MPN RHEF200
J2: Audio; PJRAN1X1U03X; Mouser Part Number 502-PJRAN1X1U03X
J3: Video; PJRAN1X1U03X; Mouser Part Number 502-PJRAN1X1U03X
J4: Conn_01x05; PinHeader_1x05_P2.54mm_Vertical
J5: RGB conn feed; PinHeader_1x03_P2.54mm_Vertical
Q1: 2SA733; TO-92_Inline; MPN 2SA733L-P-T92-B; LCSC C5310429
R1: 220; R_Axial_DIN0207_L6.3mm_D2.5mm_P7.62mm_Horizontal
R2: 330; R_Axial_DIN0207_L6.3mm_D2.5mm_P7.62mm_Horizontal
R3, R4: 5.1k; R_Axial_DIN0207_L6.3mm_D2.5mm_P7.62mm_Horizontal
R5, R7: 75 Ohm; R_Axial_DIN0207_L6.3mm_D2.5mm_P7.62mm_Horizontal
R6: 22k; R_0805_2012Metric_Pad1.20x1.40mm_HandSolder; MPN 0805W8F2202T5E; LCSC C17560
TP1: VIDEO; TestPoint_THTPad_D2.0mm_Drill1.0mm
TP2: GND; TestPoint_THTPad_D2.0mm_Drill1.0mm
TP3: +5V; TestPoint_THTPad_D2.0mm_Drill1.0mm
TP4: AUDIO; TestPoint_THTPad_D2.0mm_Drill1.0mm
U1: TPS2553DBV; SOT-23-6_Handsoldering; MPN TPS2553DBVR; LCSC C55266
USB-C1: USB4970-00-A; USB_C_Receptacle_GCT_USB4125-xx-x_6P_TopMnt_Horizontal; MPN USB4970-00-A

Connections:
/5V: C1.1, D1.1 (A1), J4.3, J5.3, R1.2, TP3.1, U1.6 (OUT)
/AUDIO_OUT: J2.2 (TIP), J4.2, TP4.1
/RGB_VIDEO: J5.1, R7.2
/VIDEO_BUF: C2.2, R5.1, R7.1
/VIDEO_OUT: J3.2 (TIP), R5.2, TP1.1
/fused_5v: C3.1, F1.1, U1.1 (IN), U1.3 (EN)
/raw_5v: F1.2, USB-C1.A9 (VBUS), USB-C1.B9 (VBUS)
GND: C1.2, C3.2, D1.2 (A2), J2.1 (SLEEVE), J3.1 (SLEEVE), J4.5, J5.2, Q1.2 (C), R3.2, R4.2, R6.2, TP2.1, U1.2 (GND), USB-C1.A12 (GND), USB-C1.B12 (GND), USB-C1.SH (SHIELD)
unnamed: J4.1, R2.1
unnamed: Q1.3 (B), R2.2
unnamed: C2.1, Q1.1 (E), R1.1
unnamed: R6.1, U1.5 (ILIM)
unnamed: R4.1, USB-C1.A5 (CC1)
unnamed: R3.1, USB-C1.B5 (CC2)

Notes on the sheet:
video audio 5v switch ground

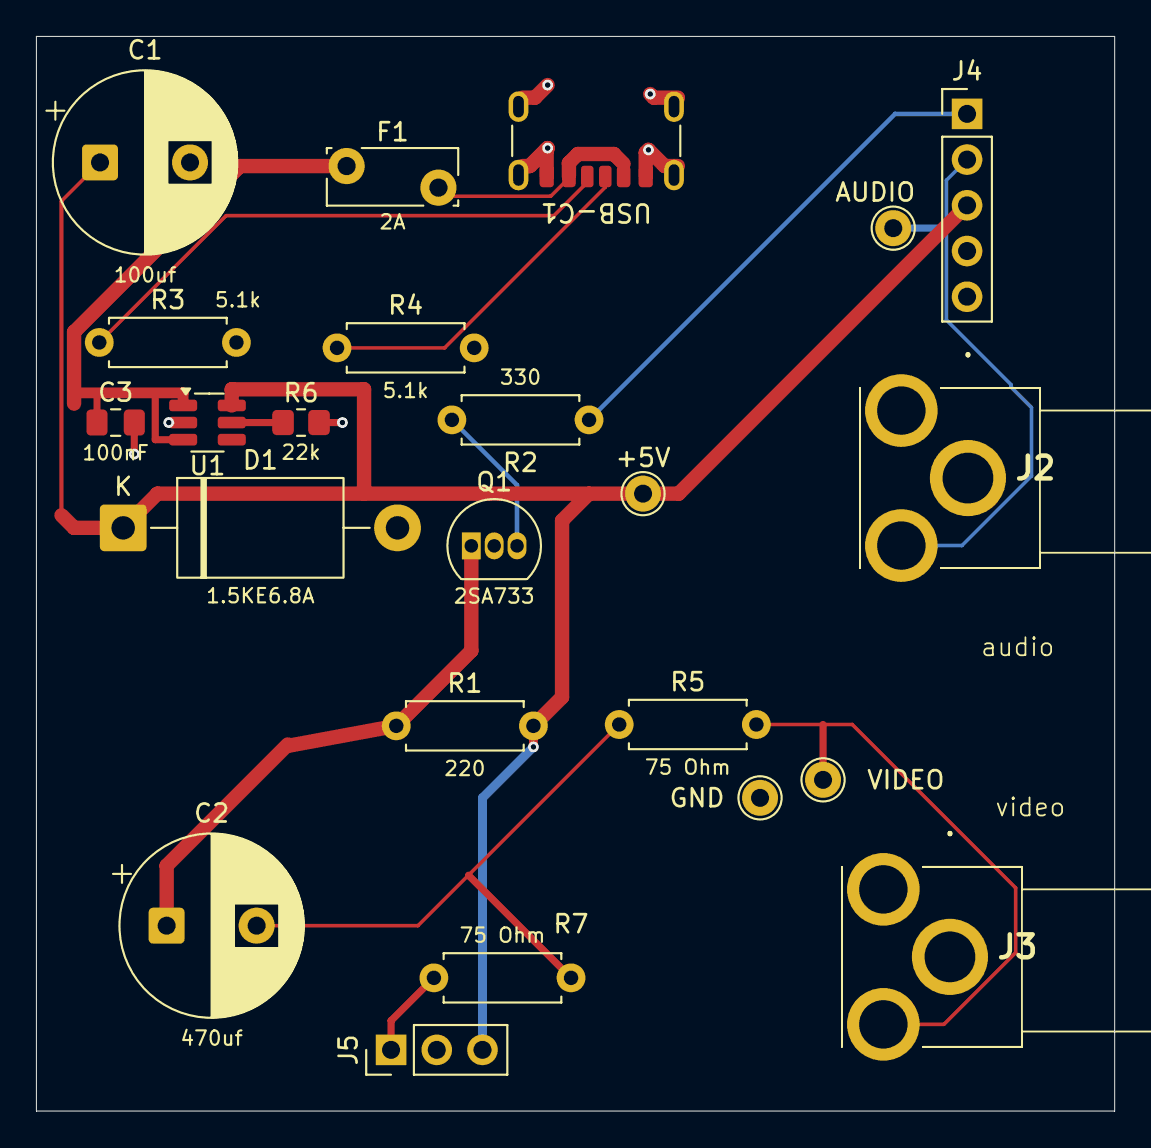
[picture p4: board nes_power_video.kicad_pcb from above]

Board: 2 copper layers, 59.9 x 59.7 mm, 23 parts (0 on the bottom side), 14 nets.

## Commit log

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2026-08-22 Switch J2/J3 to real PJRAN1X1U03X RCA jack symbols and re-route
    J2 (Audio) and J3 (Video) were still using the generic
    Connector:Conn_Coaxial symbol with the nes1:"nes connector" footprint.
    Both now use the dedicated PJRAN1X1U03X symbol and matching footprint,
    so the schematic and the board agree with the parts actually fitted.
    PCB re-routed around the updated jacks: 47 -> 70 track segments, 6 -> 4
    vias, footprint set unchanged.
    Also stop tracking KiCad transient files (_autosave-*, *.lck) that were
    committed by mistake, and add them to .gitignore.
    [nes_power_video.kicad_pcb, nes_power_video.kicad_sch]
2026-08-22 Fix Q1 emitter node shorted to +5V rail (breaks video output)
    R1 had both terminals on the /5V net, so Q1's emitter was clamped to the
    rail and C2 coupled +5V rather than video into R5/J3. The composite
    output could never have worked, on any v1 board.
    Root cause: an R2 (110 ohm) sat between /5V and the emitter node until
    2026-07-04. When it was deleted, KiCad merged its two leftover collinear
    wire stubs into a single wire from (24.13,129.54) to (24.13,194.31),
    welding the emitter node onto /5V and shorting R1 across it. Confirmed by
    exporting netlists across the KiCad auto-backups: last good at 21:17:29,
    broken at 22:15:13 the same evening.
    Schematic: removed that wire plus the six-segment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
    [BOM.csv, nes_power_video.kicad_pcb, nes_power_video.kicad_sch]
2026-08-22 Add TPS2553 eFuse for real overcurrent protection
    F1 (RHEF200, 2.0A hold / 3.8A trip) was the only overcurrent protection.
    On a console drawing roughly 0.5-0.7A a 3.8A trip point protects nothing,
    and a polyfuse takes seconds to act. U1 is now the real protection and F1
    stays as a backup in case the eFuse fails short.
    New power path:
    USB VBUS -> /raw_5v -> F1 -> /fused_5v -> U1 IN..OUT -> /5V -> load
    U1 is a TI TPS2553DBVR adjustable current-limited switch in SOT-23-6:
    resistor-programmed limit, ~3ms internal soft-start, thermal shutdown and
    reverse-voltage protection. R6 = 22k sets a ~1.18A typical limit. Note the
    relationship is inverse (I_OS ~ 25.9 / R_ILIM in kohm) - the datasheet sp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
    [BOM.csv, nes_power_video.kicad_pcb, nes_power_video.kicad_sch]
2026-08-22 Correct D1 to 1.5KE6.8A and document its limits
    The BOM listed D1 as a 1N4733A 5.6V zener in DO-41 while the schematic
    carried Diode:1.5KExxA in DO-201AE. The schematic was right: the fitted
    part is a 1.5KE6.8A, a 1500W unidirectional TVS. BOM corrected.
    Per the Vishay datasheet (88301): VWM 5.80V, VBR 6.45-7.14V at IT 10mA,
    VC 10.5V at IPPM 143A, leakage up to 1000uA at VWM. The 5.80V stand-off
    clears USB-C's 5.5V worst case, so it does not conduct in normal use.
    Recorded a limitation found while checking those numbers: the TPS2553's
    absolute maximum on IN and OUT is 7V, but this TVS is still inside its
    breakdown window at 7.14V and clamps at 10.5V under surge. D1 therefore
    protects the c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
    [BOM.csv]
2026-08-22 Correct the v1 rework procedure for the board that was actually fabbed
    The rework note added two commits ago was written against the board in the
    repo, not the one in the author's hands. The physical boards came from the
    2026-07-16 PCBWay run, whose IPC netlist shows a different and earlier
    defect:
    /5V = J4.3, F1.1, R1.1, Q1.1, C2.1, D1.1
    Net-(C1-Pad1) = R1.2, C1.1
    So R1 pad 2 is not on the rail at all - it reaches only C1. That revision
    carries two faults: Q1's emitter is clamped to the rail, and C1 is stranded
    behind R1 and therefore decouples nothing. The old note described cutting
    R1's rail traces but omitted the jumper, which would have left R1 pad 2
    floating and still p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
2026-08-22 Fix J3 video jack sleeve wired to the audio net instead of GND
    The PJRAN1X1U03X swap in 73425bb landed existing wires on different
    pins: Conn_Coaxial and PJRAN1X1U03X number and place their pins
    differently, so J3 pin 1 (SLEEVE) ended up on Net-(J2-TIP) instead of
    GND. That left the video jack's shell with no ground return and tied
    the audio signal to it.
    Schematic: drop J3.1 off the audio net and run it to the GND bus at
    y=171.45.
    PCB: delete the three B.Cu segments spurring off J2.2 to J3.1, re-net
    J3 pad 1 to GND, and refill the B.Cu ground zone. J3 pad 1 is a
    plated through-hole, so the back-layer ground pour now connects it
    directly -- no extra routing needed.
    ERC unchanged (10 warni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
    [nes_power_video.kicad_pcb, nes_power_video.kicad_sch]
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2026-08-22 Document how to confirm the v1 emitter short before reworking
    The rework steps assumed the diagnosis. Adds the two bench measurements
    that actually distinguish a defective board from a correctly wired one,
    both referenced to the +5V rail, plus how to identify Q1's legs without
    relying on the TO-92 orientation.
    Also records two tests that look diagnostic but are not: emitter to J3
    reads open either way because C2 blocks DC, and C1+ to the emitter reads
    ~330 Ohm in both wirings because R1 sits between them regardless.
2026-08-22 Clear all ERC warnings: prune dead wires, fix footprint links
    Removes 10 wires left stranded by earlier edits, including two dead
    branches (the y=175.26 GND run and its drop to y=154.94) that only
    became visible once the 1.27 mm stubs in front of them were gone.
    Every removal was gated on the exported netlist staying byte-identical,
    one wire at a time. That check earned its keep: it refused
    (27.94,194.31)->(38.1,194.31), which looks like a stub but carries Q1's
    connection. An earlier attempt that judged wires by computing pin
    positions instead got the rotation math wrong and cut live nets on U1
    and R4 -- reverted, and not how this was done.
    Also drops an orphaned junction dot at (128.27,14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
    [nes_power_video.kicad_sch]
2026-08-22 Rename to Link to Video; label test points on the silkscreen
    The test point signal names were on F.Fab, a documentation layer that is
    not part of the fabricated board, so the physical silkscreen read only
    TP1-TP4. Moves each Value field to F.SilkS beside its pad, giving both
    the refdes and the signal on the board itself:
    TP1 VIDEO TP2 GND TP3 +5V TP4 AUDIO
    TP3 and TP4 sit below their pads because above collided with their own
    reference text.
    Also retitles the project. v1 shipped as Kirby's New Dream; from v2 it is
    Link to Video. The README carries a note so the old name stays traceable
    to the v1 silkscreen, the 2026-07-16 PCBWay fab package and older commits.
    DRC unchanged: 2 pre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
    [nes_power_video.kicad_pcb]
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2026-08-22 Fix the v1 rework: it needed two jumpers, not one
    The procedure in a8d9cdf left the console unpowered. R1's left pad is a
    star point joining F1 (source), the D1 + J4.3 branch (load), and Q1's
    emitter. The two incoming rail traces are collinear, so the single
    documented cut severs both -- and the single jumper only reconnected F1.
    D1 and J4.3 were left as an orphaned island.
    Modelled against the 2026-07-10 backup, which matches the fabbed
    2026-07-16 IPC netlist exactly:
    as written : ['C1.1','F1.1','R1.2'] ['C2.1','Q1.1','R1.1'] ['D1.1','J4.3']
    corrected : ['C1.1','D1.1','F1.1','J4.3','R1.2'] ['C2.1','Q1.1','R1.1']
    Rewrites the steps around the three islands the cut produces, so the
    ju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
2026-08-25 v2 design fixes: R1 to 220R, add R2 base resistor, silkscreen values
    R1 300R -> 220R. At the assumed ~1.3V base, 300-330R supplies only ~6.2mA at
    peak white against the ~6.7mA the 150R load (R5 75R + TV 75R) needs, so the
    follower clips on bright content. 220R gives ~9.3mA.
    Add R2, 330R in series between J4 pin 1 and Q1's base, mirroring the 330R
    Nintendo places in the same position. Negligible against Q1's ~21k base input
    impedance; limits fault current into the base-emitter junction, whose reverse
    rating is only 5V. Netlist verified: Net-(Q1-E) is unchanged and 16 of 17
    existing nets are byte-identical.
    Print all resistor and capacitor values on the silkscreen. R1/R3/R4/R5/R7
    share one a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
    [BOM.csv, nes_power_video.kicad_pcb, nes_power_video.kicad_sch]
2026-08-25 Add netlist invariant check and custom DRC rules
    ERC and DRC both passed cleanly on the v1 board that shipped with Q1's emitter
    tied to /5V. Neither can see that a net is wrong, only that it is internally
    consistent. tools/check_nets.py closes that gap: it exports the schematic
    netlist, reads the PCB's pad nets, confirms the two agree, and asserts the
    invariants that matter -- above all that Q1's emitter and base touch no power
    net. Pointed at the v1 sources it reports the original fault directly.
    Run it before generating a fab package. Gerbers carry no net information, so
    by the time they exist a wrong net cannot be seen.
    nes_power_video.kicad_dru adds the geometric half: clearance betwee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
2026-08-27 Docs: correct R1 value by revision, reword two misleading notes
    Three documentation fixes, no design changes.
    The RGB output section sits under a v2 heading but still said "R1 stays
    at 330 Ω", which is the v1 value -- the v2 BOM and assembly notes both
    carry 220 Ω. The passage was written before the 220 Ω change landed, so
    its whole worked example reasoned from the old value and concluded the
    follower would sit at the edge of clipping with both cables plugged.
    Recomputed at 220 Ω using the same emitter voltage the original 8.6 mA
    figure implies (2.16 V at blanking): 12.9 mA standing against the
    ~8.7 mA two 75+75 Ω chains want, so v2 clears what v1 would not. Kept
    both caveats -- still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
    [BOM.csv]
2026-08-28 Fix zone fill and stale track left by the RCA jack rotation
    Rotating J2/J3 180 degrees to face the barrels off the board edge moved
    their pads, and the reroute left two problems that check_nets.py cannot
    see, because both are copper geometry rather than netlist membership:
    - The GND pour was never refilled, so all ten /AUDIO_OUT segments on
    B.Cu sat inside solid ground copper - an audio-to-GND short. Eight
    were geometrically inside the filled polygon; KiCad DRC reported
    0.000 mm clearance on all ten.
    - A 0.24 mm /AUDIO_OUT stub was left behind at (73.750, 38.484), which
    is J2's pre-rotation TIP pad.
    Deleted the stub and refilled the zone. DRC 17 -> 7 violations, with
    every remainin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
    [nes_power_video.kicad_pcb]
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2026-08-29 Give every part a manufacturer, MPN, datasheet and supplier link
    The TPS2553 verification from the last session only ever landed in a
    gitignored datasheet PDF: the schematic still carried U1 as a bare
    "TPS2553DBV" with an empty Datasheet field, and the exported fab BOM had
    no manufacturer at all. That is the gap that let the EN-polarity question
    stay open long enough to nearly buy the wrong part.
    Every component instance now carries Manufacturer / MPN / LCSC /
    Supplier Link / Datasheet fields, mirrored into BOM.csv as columns.
    Jellybean passives get a Spec field (tolerance, rating, package) rather
    than an invented part number - there is no MPN for a 220R axial resistor.
    Specifics:
    - U1: TP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
    [BOM.csv, nes_power_video.kicad_pcb, nes_power_video.kicad_sch]
2026-08-29 Fix Q1 silkscreen, USB-C footprint variant, and document F1's borrowed land pattern
    Q1: the silkscreen printed 2SA1015, a discontinued part. It now prints
    KSA1015, the onsemi part the BOM tells you to buy - same E-C-B pinout,
    still in production. Schematic value and BOM value follow.
    USB-C1: this was half a real bug. KiCad has no USB4970 footprint, but
    GCT's USB4970 drawing specifies exactly the USB4125 land pattern - pad
    centres 1.00/3.04/5.50 mm, widths 0.70/0.76/0.80 x 1.20 mm, shell holes
    8.64 x 3.80 mm apart at 1.10 x 1.70 mm with 0.60 x 1.20 mm slots - which
    is pad-for-pad what Connector_USB:USB_C_Receptacle_GCT_USB4125-xx-x
    carries. So the copper was always right. What was wrong is t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
    [BOM.csv, nes_power_video.kicad_pcb, nes_power_video.kicad_sch]
2026-08-29 Replace search links with verified product pages; correct D1 and Q1 sourcing
    With DigiKey and Mouser API access working, every supplier link is now a
    real product page checked against live stock, and two of the parts turned
    out to be specified wrong.
    D1 was listed as Vishay 1.5KE6.8A. That is not an orderable MPN - Vishay
    sells it as 1.5KE6.8A-E3/54, and the plain string belongs to Littelfuse,
    which is the part actually being fitted. Switched to Littelfuse and
    re-verified the numbers the README's "D1 does not protect U1" argument
    rests on, since the cited datasheet changed: VWM 5.8 V, VBR 6.45 V min and
    VC 10.5 V are identical, Ipp is 144.8 A rather than Vishay's 143 A. The
    argument stands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
    [BOM.csv, nes_power_video.kicad_sch]
2026-08-29 Switch Q1 to the 2SA733: in production, drop-in pinout, better part
    Both previous candidates are end of life, so Q1 was specified on borrowed
    time either way. The 2SA733 is in current production from UTC, shares the
    E-C-B pin order exactly - collector in the middle - so it drops into the
    existing TO-92 footprint with no layout change, and it is a better part
    for a video buffer than what it replaces:
    fT 190 MHz typ vs the 2SA1015's 80 MHz
    Cob 2-3 pF
    PC 750 mW (TO-92)
    VCEO -50 V, IC -150 mA, VEBO -5 V unchanged, so R2 still guards B-E
    Rank P is hFE 200-400, matching the ~46 uA base current measured on the
    bench at ~9.3 mA emitter, so the bias point does not move and no other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
    [BOM.csv, nes_power_video.kicad_pcb, nes_power_video.kicad_sch]
2026-08-29 Drop the stray DNP flag from J2 and J3
    Both RCA jacks carried (attr through_hole dnp), left over from planning
    PCBWay turnkey assembly. The schematic has always said populate, so this
    was a live schematic/PCB parity mismatch: an assembler reading the PCB
    could legitimately have skipped fitting both jacks.
    Found by running kicad-cli DRC with --schematic-parity, which nothing in
    this repo had been passing. That flag also reports 28 remaining parity
    issues, deliberately left in place as test material for the pre-fab gate:
    23 are missing sourcing fields on the footprints (the Manufacturer/MPN/
    LCSC data added this session lives only on the symbols, which is why the
    PCB-derived fab BOM shows no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
    [nes_power_video.kicad_pcb]
2026-08-29 Add pre-fab gate design spec
    Design for a distributable Claude Code plugin that refuses to produce a fab
    package from a board that has not passed verification. The gate owns the
    export, so the check cannot be skipped and a stale package is structurally
    impossible.
    Captures the six decisions taken while brainstorming, the classification
    policy, and an acceptance test pinned to this board at c37b56b: two blocking
    findings, twenty-nine cosmetic.
2026-08-29 Spec review fixes: drop contradictory export subcommand, feature-probe kicad-cli
    Self-review caught three things. The standalone 'export' subcommand was
    described as refusing without a passing check, which is the hash-bound
    mechanism from the approach we rejected - there was no design for how it
    would know. Dropped it: an export that can run unchecked reintroduces the
    skip the gate exists to prevent, and one that re-checks is just 'package'.
    Also defined --strict, which was listed but never explained, and replaced
    the 'minimum version TBD' placeholder with feature probing of
    kicad-cli pcb drc --help, which is more robust than a version number
    across distro builds anyway.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
2026-08-29 Correct the DNP story in the spec: deliberate, then stale
    The dnp attribute on J2/J3 was not stray. It was set on purpose when the
    plan was for PCBWay to assemble the SMD parts only, leaving the through-hole
    RCA jacks unfitted. The plan changed; the PCB kept the flag, the schematic
    never had it.
    That makes it a better motivating example than a typo would be. Parity
    checking defends against drift between two representations of the same
    intent, which is also the argument for blocking on a DNP mismatch rather
    than warning: the gate cannot know which side is correct, only that the two
    disagree about whether a part gets fitted.
    My earlier commit c37b56b calls it stray. That is wrong and this no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
2026-08-29 Add pre-fab gate implementation plan
    Ten TDD tasks building the plugin designed in the 2026-08-29 spec: model,
    DRC classification, parity classification, kicad-cli location and feature
    probing, DRC runner, reporting, manifest, atomic export, CLI wiring, and
    plugin packaging.
    Self-review against the spec caught one gap, fixed inline: the spec promises
    the gate hashes the board before and after DRC and says plainly when
    --save-board changed it, which no task implemented. Task 9 now does, with a
    test in each direction.
    Task 10 ends on an acceptance test pinned to this board at c37b56b - two
    blocking findings, twenty-nine cosmetic - with instructions to treat any
    other verdict as a bug in the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
2026-08-29 fix(prefab-gate): use the real KiCad parity message set
    Extracted the authoritative parity message list from the KiCad 10
    _pcbnew.kiface binary. "not in schematic" is not a real DRC message
    (it only appears in the footprint properties GUI panel) and is
    removed; there is no extra-footprint parity message at all. Added
    three missing structural messages (pad/pin mismatches, pad missing
    net) to BLOCKING_PARITY and two missing metadata messages (symbol
    value mismatch, field differs) to COSMETIC_PARITY.
    Verified no blocking substring is contained in any real cosmetic
    message, including the two "'%s' settings differ" cases which still
    separate correctly on their distinct quoted text.
2026-08-29 feat(prefab-gate): run DRC with parity and zone refill, parse JSON
    run_drc drives kicad-cli with --format json --severity-all
    --schematic-parity --refill-zones --save-board, writing to a temp
    file and returning the parsed dict. --exit-code-violations is
    deliberately omitted so a non-zero exit only ever means kicad-cli
    itself failed, never that it found problems; that distinction is the
    gate's own policy layer, applied later by classify().
    json/tempfile imports hoisted to the module top alongside the
    existing imports rather than appended mid-file.
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2026-08-29 fix(prefab-gate): fail closed when schematic parity cannot run
    kicad-cli exits 0 when it cannot load the schematic for parity tests: it
    prints "Failed to fetch schematic netlist for parity tests." to stderr and
    emits "schematic_parity": []. A board whose schematic is missing, renamed or
    unannotated therefore produced a clean parity result, a PASSED verdict,
    exported gerbers and a manifest asserting all of it — with no record that
    parity never ran. That is the exact fault class this gate exists to catch.
    run_drc now fails closed on both sides of the invocation: it refuses to run
    at all when the expected .kicad_sch is absent, and it raises when kicad-cli's
    stderr carries either parity-failu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
2026-08-29 fix(prefab-gate): enforce the 0/2/3 exit contract on every path
    Three ways out of main() ignored the contract the spec fixes at 0 clean,
    2 blocked by findings, 3 environment problem:
    - A nonexistent board raised FileNotFoundError out of manifest.sha256, past
    `except KicadUnavailable`, giving a traceback and exit 1. Malformed DRC JSON
    and a failed manifest write did the same. main() now validates the board
    path up front and catches OSError and json.JSONDecodeError, reporting each
    as exit 3 with a readable message.
    - argparse exits 2 on a usage error, which in CI is indistinguishable from a
    board that failed verification. GateArgumentParser.error() exits 3 instead:
    a mistyped flag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
2026-08-29 fix(prefab-gate): publish the manifest atomically with the package
    export_package published with os.replace and the CLI then wrote manifest.json
    into the already-published directory. A failure in that window left a
    complete-looking fab package on disk with no receipt — no board hash, no
    record of what the gate waved through, nothing to audit months later.
    export_package now takes an optional on_staged callback, invoked with the
    staging directory after all four exports succeed and before the publish. The
    CLI passes a callback that builds and writes the manifest into staging, so
    one os.replace publishes the package and its receipt together, and a failure
    anywhere before it leaves nothing at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
2026-08-29 fix(prefab-gate): record what the gate was told not to look at
    The spec says exclusions are "counted and otherwise ignored", but classify()
    dropped them with a bare `continue` and no count reached the verdict, the
    report or the manifest. The DRC JSON's ignored_checks array was read by
    nothing at all — this board disables five check categories in its project
    file, and the gate could print PASSED with no trace of that.
    Verdict now carries `excluded` and `ignored_checks`; classify() populates
    both; render_text prints one "Not checked:" line naming the disabled rule
    keys; render_json and the manifest carry them as data. A receipt whose job is
    "what did the gate knowingly allow past" has to re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
2026-08-29 fix(prefab-gate): use the plugin layout Claude Code actually loads
    plugin.json sat at the plugin root. Claude Code reads
    .claude-plugin/plugin.json, and adding this directory as a marketplace needs
    .claude-plugin/marketplace.json beside it — neither existed, so the plugin was
    not installable at all. Layout now matches the installed kicad-happy example.
    SKILL.md told the agent to run `python3 scripts/prefab_gate.py`, a relative
    path that resolves against the user's project directory, where the gate does
    not live. It now uses ${CLAUDE_PLUGIN_ROOT}/scripts/prefab_gate.py and says
    why.
    SKILL.md and README also now describe what exit 3 covers, that `check` can
    still rewrite zone fills, and th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
2026-08-29 docs(prefab-gate): correct the acceptance count and the check-produces-nothing claim
    The spec and the plan both stated "29 cosmetic" in the acceptance test while
    their own breakdown — 4 + 2 + 23 + 4 — sums to 33. The real verdict is
    2 blocking / 33 cosmetic, verified twice against the board. Left uncorrected,
    a future reader would "fix" a correct gate to reproduce a wrong number.
    The spec also said `check` "produces no files" while its Decisions table
    mandates --refill-zones --save-board unconditionally, which can rewrite the
    board. It now says `check` produces no *package*, may rewrite zone fills, why
    that is deliberate, and that the change is announced.
    render_text's blocked headline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
2026-08-30 Clear both pre-fab gate blockers: J5's library prefix and TP1's courtyard
    The gate refuses to export while either of these stands.
    J5 was added in a08b93d with a bare footprint identifier,
    "PinHeader_1x03_P2.54mm_Vertical", while its symbol asks for
    "Connector_PinHeader_2.54mm:PinHeader_1x03_P2.54mm_Vertical". The pads on
    the board are identical to the library part, so only the string was wrong.
    TP1's 1.5mm courtyard sat 0.935mm from the corner of J3's, overlapping it
    by 0.565mm. TP2 fixes a 3mm minimum to TP1's left and J3 blocks right and
    below, so TP1 moves 1mm up to (62, 59) and the VIDEO_OUT track start
    follows it. This breaks the TP1/TP2 row alignment, which was cosmetic.
    Zone fills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
    [nes_power_video.kicad_pcb]
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
